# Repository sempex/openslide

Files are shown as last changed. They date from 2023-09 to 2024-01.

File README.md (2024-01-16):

# Openslide

OpenSlide is an Open-Source Camera Slider build with cost effective and well available components.

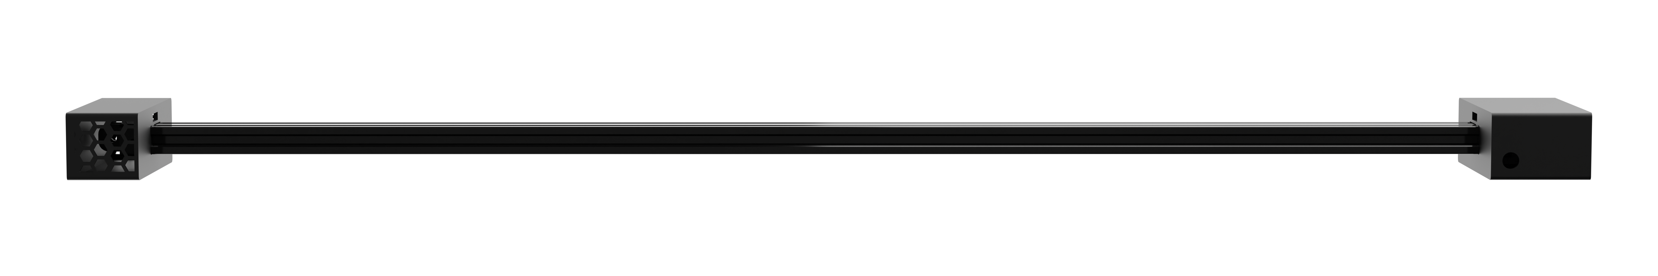
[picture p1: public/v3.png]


# How to build your own OpenSlide
Here is a basic overview on how to build your own slider. For more detailed instructions view the german [docs](doc.pdf) of the project.

## Item list

- [Rails]()  
    We use standardized V-slot aluminum extrusions as rails. These are easy to process and
    easy to obtain.
- [Motor](https://a.aliexpress.com/_mMwP7J2)  
    In order for the cart to automatically travel on the rails, it needs a motor. We have opted for the Nema 17 42 Stepper Motor.
- [Cog belt](https://a.aliexpress.com/_mKwwtJ2)  
    The V-belt is looped around the camera slider; it is responsible for enabling the cart to move along the rails with the help of the motor. Since we couldn't use a standard size, we opted for a set. This allows us to adjust the V-belt ourselves, adapting it to our specific size. This not only ensures a secure fit in terms of size but also allows us to experiment and optimize, as we can adjust the tensile strength ourselves.
- [Cart](https://a.aliexpress.com/_mOrK72g)  
    The cart is pulled back and forth on the rails by the V-belt, making it the moving element in our construction. Ultimately, the camera is attached to the cart, allowing it to move back and forth as desired. The cart has a standard size that corresponds to the rails. Additionally, it is adjustable depending on the type of rails chosen. This ensures that it works for our project.
- [Arduino]()  
    To implement the logic on the camera slider, we use an Arduino Micro-Controller. This has the advantage of being very small while providing all the necessary connections.
- [Power supply](https://a.aliexpress.com/_mNNVPCc)  
    To drive the motor, we require more power than what we can supply through the USB interface. Therefore, we need an external power supply to ensure the proper functioning of the motor.
- [End switch]()  
    To determine the position of the cart on the slider in the code, we need to perform calibration at the beginning. For this purpose, we require two switches, each attached at the start and end of the slider. These switches will notify us when there is contact with the cart.
- [Motor Driver](https://a.aliexpress.com/_m0FvBMk)  
    It is used for communication with the motor, issuing commands such as speed, current consumption, precision, and temperature to the motor.
- [Capacitor]()  
    Capacitors store electrical charges and the associated electrical energy temporarily. This ensures that a constant amount of current reaches the end device, thereby eliminating fluctuations in voltage.
- [Accessories]()  
    To attach various components, we need various screws and hot glue, among other things. We already had these utensils on hand.

## 3D Printing
Print the parts form the `cat/renders/` Folder of the GitHub Project

## Build
### Connect Arduino with Motor 
You can use the following Plan to connect the Motor with the Arduino and the driver.
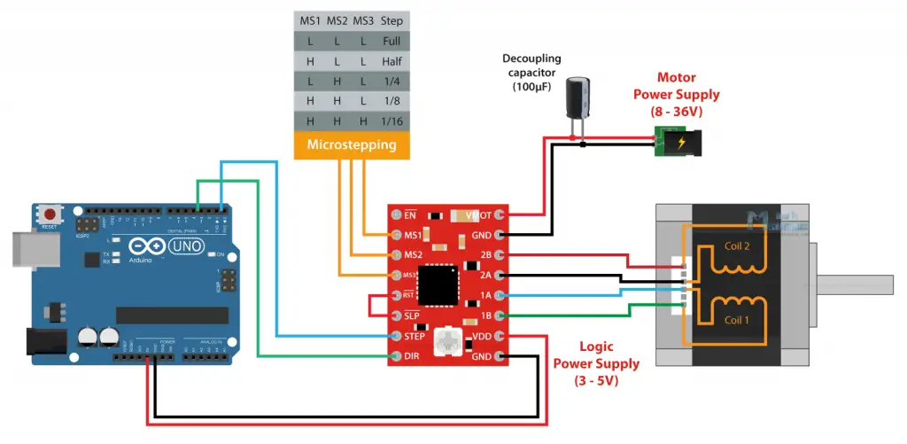
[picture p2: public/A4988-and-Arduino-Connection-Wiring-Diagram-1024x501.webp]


If you don't want to make changes to the arduino script, use following Ports:

```text
stepPin 5
dirPin 4
```

### Connect Switches
Connect the Switches to the Arduino, use following ports if you don't want to make changes to the script.

```text
#define btnOne 14
#define btnTwo 13
```

### Put everything together

Assemble the Rest of the parts using the Image of the Slider.

## User Interface

You can use our user Interface deployed on [openslide.vercel.app](openslide.vercel.app) or deploy it yourself using the node Application in `/src` directory.

Start using the Slider. Enjoy the Experiance.

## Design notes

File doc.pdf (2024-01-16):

Allgemeinbildender Unterricht

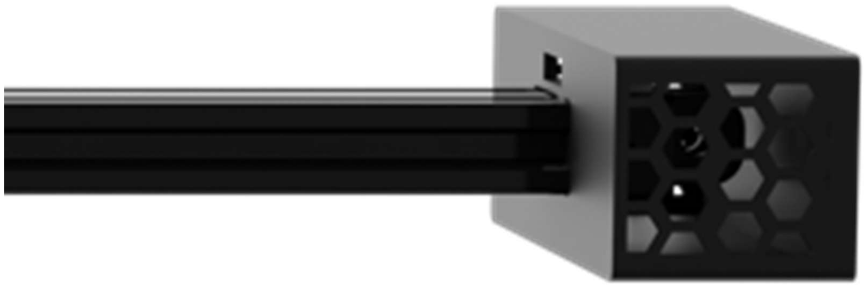
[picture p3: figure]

Abgabe: 21.12.2023 | Lehrperson:-

Klassenthema Faszination

# Entwickeln eines motorisierten Kamera-Slider (OpenSlide)

Noé Krebs, Tim Reber

Vertiefungsarbeit | OpenSlide - Kamera Slider
Tim Reber, Noé Krebs | 2

Tim Reber, Noé Krebs | 3

## Inhalt

Tim Reber, Noé Krebs | 4

Vertiefungsarbeit | OpenSlide - Kamera Slider

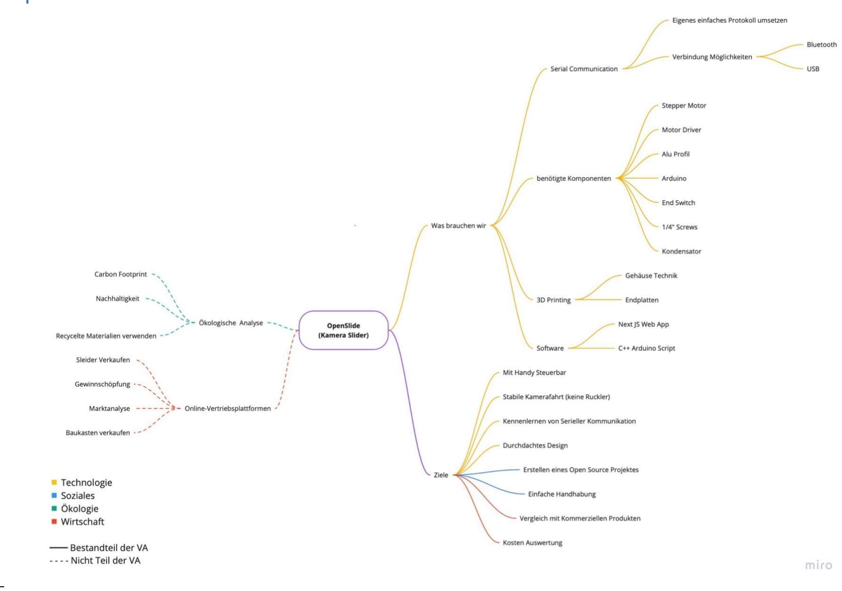
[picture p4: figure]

Tim Reber, Noé Krebs | 5

## 1. Mindmap¹

1

Mindmap, selbst erstellt

Tim Reber, Noé Krebs | 6

## 2. Einleitung²

Der motorisierte Kamera-Slider ist ein bedeutendes Werkzeug in der Videoproduktion, insbesondere für Filmemacher, die einzigartige Aufnahmen anstreben. Mit präzisen Schienen und einem leistungsstarken Motor ermöglicht dieser Slider exakte Kamerabewegungen bei anpassbarer Geschwindigkeit und Einstellungen. Diese Arbeit untersucht die technischen Aspekte des motorisierten Kamera-Sliders im Kontext der faszinierenden Welt der Videoproduktion und Technik, perfekt passend zum Klassenthema "Faszination".

Wir haben uns für dieses Projekt entschieden, da uns sowohl die Welt der Videographie als auch die Technik begeistert.

Das Projekt Open Source zu machen war für uns ein Anliegen, da wir in unserm Hobby als Entwickler viel Open-Source-Software verwenden und wir gerne auch mal etwas zu dieser Community beitragen möchten.

### 2.1. Ausganslage

In unserem Projekt wollen wir einen motorisierten Kamera-Slider selbst bauen (OpenSlide). Dieser besteht aus vorherig bestellten Einzelkomponenten, welche wir dann nach eigens kreiertem Konzept zusammenbauen. Damit man den Kamera-Slider auch ansteuern und verwalten kann, gibt es ein Web-UI, wo man Distanz, Geschwindigkeit, vordefinierte Modi und weitere Parameter konfigurieren kann. Der Code für das Web-UI wird komplett selbst geschrieben. Das gilt nicht nur für das Web-UI selbst, sondern auch für die Logik, welche der Kamera-Slider bereitstellen muss, damit die Integration mit dem Web-UI funktioniert. Damit diese beiden Komponenten zusammen kommunizieren können, werden wir ein simples Protokoll schreiben. Am Ende des Projekts wird es möglich sein, den Kamera-Slider via USB-Kabel mit einem PC zu verbinden und via Web-UI die Aktionen, welche der Kamera-Slider ausführen soll, zu bestimmen. Es wird möglich sein, eine Kamera auf dem Kamera-Slider zu befestigen. Dies via standardisiertem Schraubsystem, welches ermöglichen soll, dass möglichst viele Kameras mit unserem Slider kompatibel sind.

### 2.2. Abgrenzung

In unserem Projekt beschränken wir uns darauf, dass die Kamera nicht in verschiedene Richtungen verstellbar, sondern fix auf dem Kamera-Slider angebracht ist. Dies ist bei anderen Lösungen möglich, wir werden dies aber nicht realisieren, weil es den Zeitrahmen dieses Projekts sprengen würde.
Das Web-UI, um den Slider zu verwalten, wird öffentlich für alle erreichbar sein. Es wird keine Prüfung geben, ob man im Besitz einer unserer Kamera-Slider ist.
Das Web-UI muss nur auf offiziell unterstützen Chrome basierten Browsern funktionieren, alles andere wird von unserer Seite her nicht gewährleistet.

2

Einleitung, Selbst erstellt

Tim Reber, Noé Krebs | 7

## 3. Zielformulierungen³

- Unser Ziel ist es einen motorisierten Kamera-Slider zu entwickeln. Dabei setzen wir auf herkömmliche, erschwingliche und leicht zugängliche Komponenten. Unsere Fortschritte dokumentieren wir sorgfältig mit Bild und Text. Anschliessend veröffentlichen wir die Ergebnisse (Pläne / Code / Bilder) in einem GitHub Repository.
- Wir wollen einen umfassenden Kostenvergleich für unseren Slider im Vergleich zu ähnlichen kommerziellen Produkten erstellen. Hierzu werden wir Recherchen zu den Preisen herkömmlicher Komponenten durchführen. Diese vergleichen wir mit verfügbaren kommerziellen Kamera-Slider-Produkten im Internet.

Die Ergebnisse dieses Vergleichs werden wir in einer klaren und visuell ansprechenden Form präsentieren. Am Ende dieses Vergleichs werden wir eine Schlussfolgerung ziehen, die die Unterschiede in den Kosten zwischen unserem Slider und den kommerziellen Alternativen zusammenfasst.

- Um die technischen Grenzen unseres Sliders zu erkunden, führen wir eine Vielzahl von Tests durch. An verschiedenen Standorten nutzen wir professionelle Kameras in Kombination mit unserem Slider, um Aufnahmen anzufertigen.

Die Ergebnisse dieser Tests werden in einem eigens erstellten Bewertungsraster mit fertigen Kamera-Silder aus dem Internet verglichen und präsentiert. Hierbei werden die einzelnen Punkte für die ausgewählten Produkte auf einer Skala bewertet. Diese umfassende Bewertung erlaubt uns, die technischen Möglichkeiten unseres Sliders gründlich zu untersuchen.

3

Zielformulierung, Selbst erstellt

Tim Reber, Noé Krebs | 8

## 4. Grobplanung⁴

4

Grobplanung, Selbst erstellt

Wo-che | Arbeitsschritte | Verantwortlich* | Bemerkungen
KW 43 | Start mit der VA - Überprüfen und finalisieren der Ma-terialliste - Bestellen der Teile - Serial Protokoll ausbauen - Arbeitsjournal nachführen | Noé, Tim | Serielles Protokoll wird in NodeJS und in C++ implementiert. Alle benötigten Kompo-nenten werden online, entsprechend unserer Materialliste bestellt.
KW 44 | - Initialisierung des Web-UI Projekt - Prototyp des Web-UI deployen (im Internet verfügbar machen) - Definieren und dokumentieren der Anforderungen an das Web-UI | Noé, Tim | Erstellen eines Next.Js Projekts für das Web UI. Erste Features werden bereits gemäss Anfor-derungen eingebaut.
KW 45 | - Entwurf des 3D Slider-Modell - Modell für 3D Druck bereit machen (Slicen). - Modell drucken - Beginn Konstruktion Openslide | Noé, Tim | Eine erste Version des Modells wird konstruiert und gedruckt. Es wer-den weitere Iterationen folgen, nachdem wir mit diesem Modell Tests durchgeführt haben. 3D Modelle werden wir in Fusion 360 konstru-ieren. Wir beginnen den Bau des Sliders mit den be-stellten Komponenten. Die Schaltkreise wer-den gelötet.

Tim Reber, Noé Krebs | 9
KW 46 | - Weitere Iterationen des 3D Mo-dells konstruieren - Rendern des 3D Modells für das Web-UI - Einbinden des 3D Modells ins Web-UI | Noé, Tim | In Blender werden wir ein Produktbild ren-dern.
KW 47 | - Entwicklung der Logik auf Seite des OpenSlides | Noé, Tim | Bis zu diesem Zeit-punkt haben wir die Lo-gik für den User aus dem Web-UI entwickelt. Damit diese Aktionen umgesetzt werden kön-nen, müssen wir noch den Code für den Slider in C++ schreiben.
KW 48 | - Weiterführung der Slider Entwick-lung - Abstimmung WebUI – Silder | Noé, Tim | WebUI und Slider Firm-ware müssen aufeinan-der abgestimmt wer-den.
KW 49 | - Testen des Sliders zusammen mit dem Web-UI - Testen der Performance des Sli-ders - Beheben allfälliger Bugs | Noé, Tim | Wir müssen den Slider auf Fehler im Zusam-menhang mit dem Web-UI testen. Wir wollen herausfin-den, wo die Grenzen unseres Sliders liegen. Was ist die maximale Geschwindigkeit? Dies wäre eine berechtigte Frage, die man hier stellen könnte. Falls Fehler auftauchen müssen wir diese behe-ben.

Tim Reber, Noé Krebs | 10

*Hauptverantwortlicher: Fett. Pro Woche wird ein Hauptverantwortlicher festgelegt. Wir arbeiten jeweils an denselben Aufgaben.

KW 50 | - Finalisierung und Optimierungen des Sliders | Noé, Tim | Hier werden letzte Opti-mierungen vorgenom-men. Falls unerwartete Feh-ler in unserem Code oder in unserer Kon-struktion auftreten, ha-ben wir hier noch Zeit diese zu beheben.
KW 51 | - Abgabe der Arbeit - Kreieren von Aufnahmen | Noé, Tim | Abgabe in zwei unter-schiedlichen Ausfüh-rungen: PDF und bearbeitetes Worddokument Falls nach der Abgabe noch Zeit übrig bleibt, wollen wir mit dem Sli-der eigene Aufnahmen machen.

Tim Reber, Noé Krebs | 11

# Hauptteil

In diesem Kapitel beschreiben wir, wie wir das Endprodukt gebaut haben und gehen auf die einzelnen Aspekte des Projekts ein.

Tim Reber, Noé Krebs | 12

## 5. Konzeptionierung 5

In folgendem Kapitel haben wir die Planung und die Informationsbeschaffung beschrieben.

### 5.1. Materialliste⁶

In der folgenden Materialliste sind alle relevanten Teile zu finden, die wir für den Bau des Sliders eingeplant und bei Bedarf bestellt haben.

Tabelle 1 Material
Komponente | Beschreibung | Link
Schienen | Als Schienen verwenden wir standardisierte V-Slot Alumi-
| nium Extrusions. Diese sind einfach zu verarbeiten und
| leicht zu beschaffen.
Motor | Damit das Cart auch automatisch auf den Schienen fahren
| kann, braucht es einen Motor. Wir haben uns für den Nema
| 17 42 Stepper Motor entschieden.
Keilriemen | Der Keilriemen wird einmal um den Kamera-Slider ge-
| spannt, er ist dafür verantwortlich, dass das Cart auf den
| Schienen mit Hilfe des Motors überhaupt fahren kann. Da
| wir nicht auf eine Standardgrösse zurückgreifen konnten,
| haben wir uns dazu entschieden ein Set zu verwenden.
| Dies ermöglicht, den Keilriemen selbst zu spannen. Damit
| können wir ihn auf unsere bestimmte Grösse anpassen.
| Das hat einerseits den Vorteil, dass er von der Grösse her
| sicher passt. Andererseits können wir dadurch auch ein we-
| nig experimentieren und optimieren, da wir die Zugfestigkeit
| selbst einstellen können.
Cart | Das Cart wird durch den Keilriemen auf den Schienen hin
| und her gezogen, das heisst es ist das bewegende Element
| in unserer Konstruktion. Darauf wird dann schlussendlich
| die Kamera befestigt, damit diese in der Lage ist, nach Be-
| lieben hin und her zu fahren. Das Cart hat eine Standard-
| grösse, welche den Schienen entspricht. Es ist ausserdem
| verstellbar, je nach dem für welche Schienen man sich ent-
| schieden hat. Dadurch können wir uns sicher sein, dass es
| für unser Projekt funktioniert.
Arduino | Damit wir die Logik auf Seite des Kamera-Sliders imple-
| mentieren können verwenden wir einen Arduino Micro-Con-
| troller. Dieser hat den Vorteil, dass er sehr klein ist und alle
| benötigten Anschlüsse bietet.
Netzteil | Um den Motor anzutreiben, brauchen wir mehr Strom als
| wir über die USB-Schnittstelle zur Verfügung stellen kön-
| nen. Deswegen brauchen wir ein externes Netzteil damit
| der Motor ordnungsgemäss funktioniert.
End-Schalter | Damit wir im Code wissen können wo sich das Cart auf
| dem Slider befindet, müssen wir am Anfang eine Kalibrie-
| rung durchführen. Dafür benötigen wir zwei Schalter, wel-
| che jeweils am Anfang und am Ende des Sliders befestigt

5

Konzeptionierung, Selbst erstellt
6

Materialliste, Stark bearbeitet

Tim Reber, Noé Krebs | 13

sind und uns benachrichtigen, wenn es einen Kontakt mit dem Cart gibt.
Motor-Treiber | Er wird für die Kommunikation mit dem Motor eingesetzt
| und befiehlt dem Motor: Geschwindigkeit, Stromverbrauch,
| Präzision und Temperatur.
Kondensator | Kondensatoren speichern kurzfristig elektrische Ladungen
| und die damit verbundene elektrische Energie, dies sorgt
| dafür, dass konstant gleich viel Strom am Endgerät an-
| kommt und somit Schwankungen in der Spannung elimi-
| niert werden.
Zubehör | Um diverse Komponenten zu befestigen, benötigen wir un-
| ter anderem diverse Schrauben, sowie Heissleim. Diese
| Utensilien hatten wir bereits zur Hand.

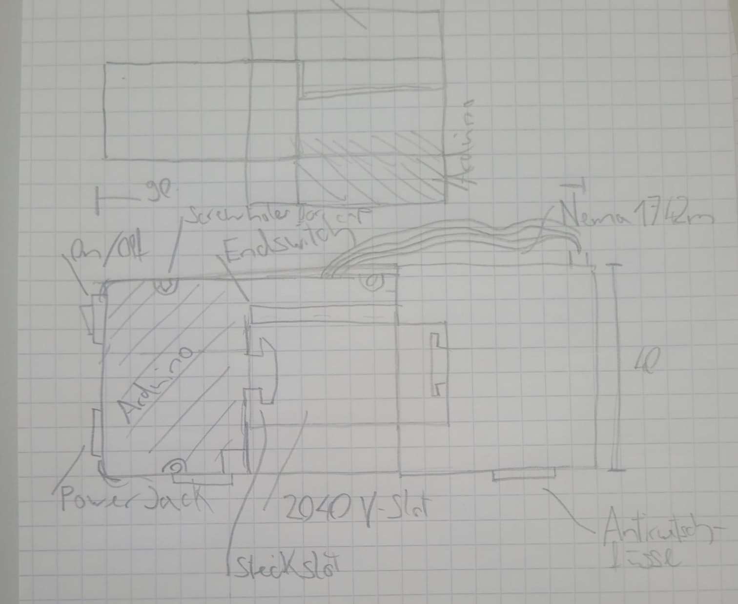
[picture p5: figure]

Tim Reber, Noé Krebs | 14

### 5.2. Technische Aspekte

In diesem Kapitel gehen wir genauer auf die technische Planung ein.

5.2.1. 3D Modellierung

Damit wir unser Projekt richtig planen und uns für die richtigen Komponenten entscheiden konnten, mussten wir eine Idee manifestieren, wie genau der Kamera-Slider schlussendlich aussehen soll.

Zum Brainstorming haben wir von Hand einige Skizzen erstellt, bis wir uns schlussendlich auf diesen groben Entwurf geeinigt haben. Dieser eignet sich am Besten, da alles auf möglichst kleinem Raum untergebracht werden kann. Ob alles genau so passen würde, wie wir uns das vorgestellt haben, ist noch unbekannt.

Abbildung 1 Originalfotografie der ersten Skizze

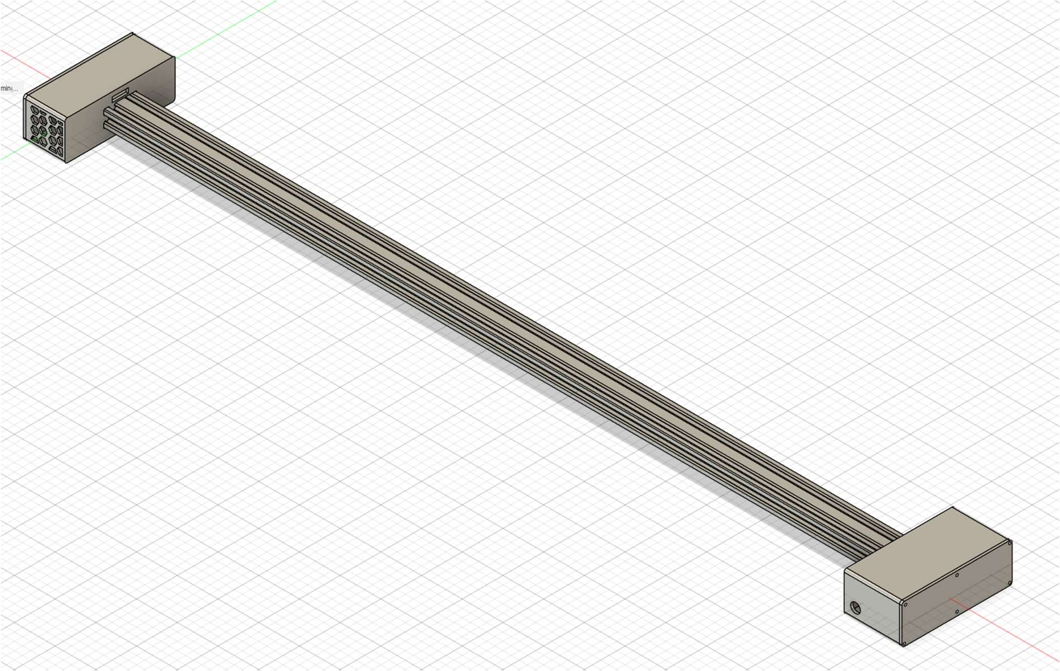
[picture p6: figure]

Tim Reber, Noé Krebs | 15

Mit dieser Skizze als Basis haben wir uns die Zeit genommen ein 3D Modell zu zeichnen. Um diese Modelle erstellen zu können, verwenden wir die Community Version der CAD Software Fusion 360 von Autodesk. Das Modell wurde Millimeter genau gezeichnet, da diese Teile mit dem 3D Drucker ausgedruckt werden. Um diese komplexen Teile passgenau drucken zu können, waren mehrere Iterationen nötig.

Abbildung 2 Finales 3D Modell des Sliders

So stellen wir uns den fertigen Kamera-Slider vor. Im rechten 3D gedruckten End-Teil, oder von uns auch Control Center genannt, wird die ganze Elektronik untergebracht, unter anderem der Motor und das Arduino, welche für die Funktionalität des Sliders verantwortlich sind. Links in der Abbildung ist das andere End-Teil. Dort ist nur ein End-Schalter und eine Umlenkrolle für den Keilriemen eingebaut.

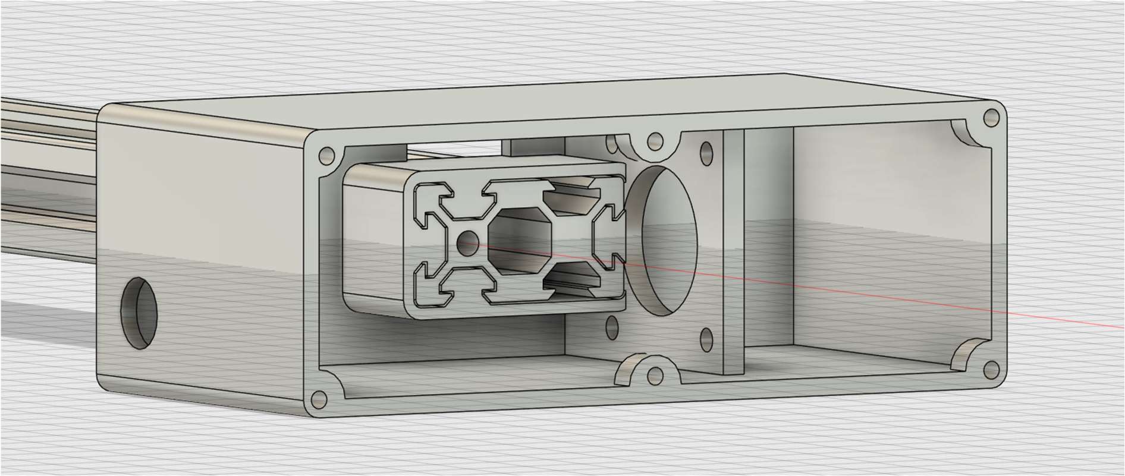
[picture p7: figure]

Tim Reber, Noé Krebs | 16

Abbildung 3 End-Teil mit Elektronik (Control Center)
Das Control Center besteht aus drei separaten Teilen, welche nach dem Ausdrucken zusammengesteckt werden können. Zur Einfachheit der Montage wird die Motorplatte unabhängig vom Gehäuse konstruiert. Der Motor wird auf der rechten Seite mit vier Schrauben an der Motorhalterung angebracht. Der Keilriemen wird später durch die Aussparungen in der Aluminiumschiene geführt.

Der Deckel kann mit vier bis sechs Schrauben am Gehäuse befestigt werden. Dies ist für beide End-Teile gleich.

Abbildung 4 End-Teil mit Umlenkrolle

7

Abbildung 6 Control Center Seitenansicht
Auf der linken Seite des Control Centers wird später die Strombuchse für den Slider montiert.

7

Power Jack (www.aliexpress.com) 19.12.2023, direkt übernommen

Abbildung 5 Strombuchse

Tim Reber, Noé Krebs | 17

Damit wir uns den Slider etwas besser vorstellen können, haben wir das 3D-Design in die Open Source Software Blender importiert.

Blender ist eine Grafiksoftware, mit welcher man Körper modellieren und animieren kann. Ausserdem kann man damit auch realistische Darstellungen von 3D Modellen erstellen. Wir haben uns genau diese Funktion zunutze gemacht und haben ein Bild des Modells erstellt.

Abbildung 7 Rendering des Sliders

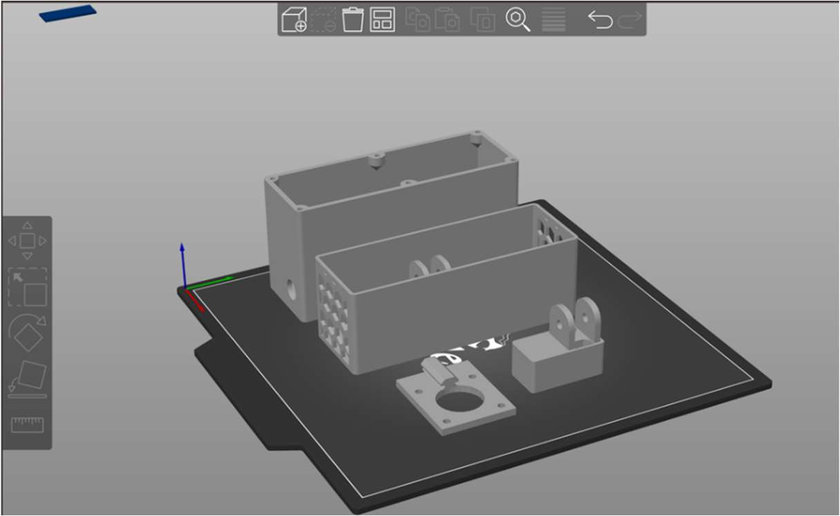
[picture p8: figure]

Tim Reber, Noé Krebs | 18
5.2.2. 3D-Druck

Im folgenden Abschnitt erklären wir, wie wir unsere zuvor erstellten 3D Modelle auf den 3D Druck vorbereiten.
Um ein Modell drucken zu können, muss es zuerst in einem Slicer aufbereitet werden. Wir verwenden den Open Source Slicer «Prusa Slicer» von Prusa. Im Slicer muss der Drucker und die Materialen, mit dem das Modell gedruckt wird, konfiguriert werden. Ausserdem kann jedes Detail des Druckvorganges genau eingestellt werden. Das ist aber in den meisten Fällen überflüssig, da der Slicer bereits sehr solide Standardwerte bietet.

Da das Druckbett zu klein ist um alle Teile gleichzeitig zu drucken, müssen wir verschiedene Druckaufträge erstellen. Im ersten Auftrag ziehen wir die wichtigsten Teile auf das Druckbett.

Abbildung 8 Druckaurag 1

Wir haben lediglich die grundlegenden Einstellungen für den Druck vorgenommen. Hierzu zählen insbesondere die Auswahl der Düsengrösse (0.20mm), die Konfiguration des Druckers (Creality Ender-3), sowie die Festlegung des verwendeten Filaments (PLA).

Für diese Einstellungen sind wiederum Standardwerte definiert, wie zum Beispiel die Flussmenge für das Filament oder die Druckbettgrösse für den Drucker. Es ist jedoch nicht notwendig, diese selbst zu definieren, da entsprechende Profile vom Slicer bereitgestellt werden.

Abbildung 9 Slicer Grundeinstellungen

Nachdem alle Teile eingefügt und die entsprechenden Einstellungen vorgenommen wurden, ist es nun an der Zeit, das Projekt zu "slicen". Dieser Prozess bezeichnet die Umwandlung des 3D-Modells in Anweisungen, die der 3D-Drucker verarbeiten kann.

Anschliessend kann der Auftrag an den Drucker geschickt und gestartet werden.

Tim Reber, Noé Krebs | 19

### 5.2.3. Eigenes Protokoll

Das Problem bei der seriellen Kommunikation, so wie wir sie verwenden ist, dass jeder Charakter als einzelnes Byte ans Arduino gesendet wird.

Wenn man das Wort: “beispiel” ans Arduino sendet, interpretiert es jeden Buchstaben einzeln: «b», «e», «i», «s», «p», «i», «e», «l». Das ist für unseren Anwendungszweck nicht geeignet. Wenn wir zum Beispiel eine Position vom Web-UI ans Arduino senden wollen, wird bereits mehr als ein Zeichen in Anspruch genommen, da wir einen Startpunkt und einen Endpunkt senden müssen.

Damit wir mehr als nur ein einzelnes Zeichen senden oder empfangen können, haben wir ein simples Protokoll entwickelt. Wir haben im Code definiert, dass wir auf ein Startzeichen warten. Dies ist in unserem Fall «<» kleiner als. Das heisst, wenn ein solches Zeichen kommt, wissen wir, dass jetzt eine neue Nachricht beginnt.

Wir haben ebenfalls ein Schlusszeichen definiert: «>» grösser als. Wenn dieses Zeichen erscheint, wissen wir, dass die Nachricht komplett ist. Allen Charakteren, welche sich jetzt zwischen diesen beiden Zeichen befinden, werden nun zusammengefügt und entsprechen der ganzen Nachricht.

Zum Verständnis: Wenn wir jetzt eine Start-und End-Position ans Arduino senden wollen, müsste die Nachricht wie folgt aussehen: «<MOVE:start=10,end=35>». MOVE ist der auszuführende Befehl. Start und end sind beliebige Parameter die zusätzlich zum Befehl übergeben werden. Alles zusammen entspricht einer ganzen Nachricht.

Bandbreite

Da unser Protokoll auf Buchstaben basiert, braucht es viel mehr Bandbreite als ein Bit basiertes Protokoll. Wir sind diesen Kompromiss eingegangen, da bei uns die übertragene Datenmenge klein ist und es verständlicher ist.

Um mit unserem Protokoll diese Nachricht (<MOVE:start=10,end=35>) zu übermitteln, braucht es rund 25 Bytes.

Mit einem rein binären Protokoll könnte man diese Zahl auf unter 5 Bytes bringen, da keine unnötigen Informationen übertragen werden, die nur zur Verständlichkeit dienen.

Error Korrektur

Bei der Übertragung von Daten besteht immer die Möglichkeit, dass einzelne Buchstaben oder Bits fehlerhaft übertragen werden. Das bedeutet, dass der Empfänger nicht genau das empfängt, was gesendet wurde. Um dies zu verhindern, integrieren viele Protokolle sogenannte Fehlerkorrekturmechanismen. Diese ermöglichen es, bis zu einem bestimmten Prozentsatz an korrekten Daten die ursprüngliche Nachricht wiederherzustellen.

Auch hier hat unser Protokoll einen Nachteil. Allerdings spielt es bei solch kleinen Datenmengen und für unsere Anwendungen kaum eine Rolle, wenn wir keine Error Korrektur verwenden.

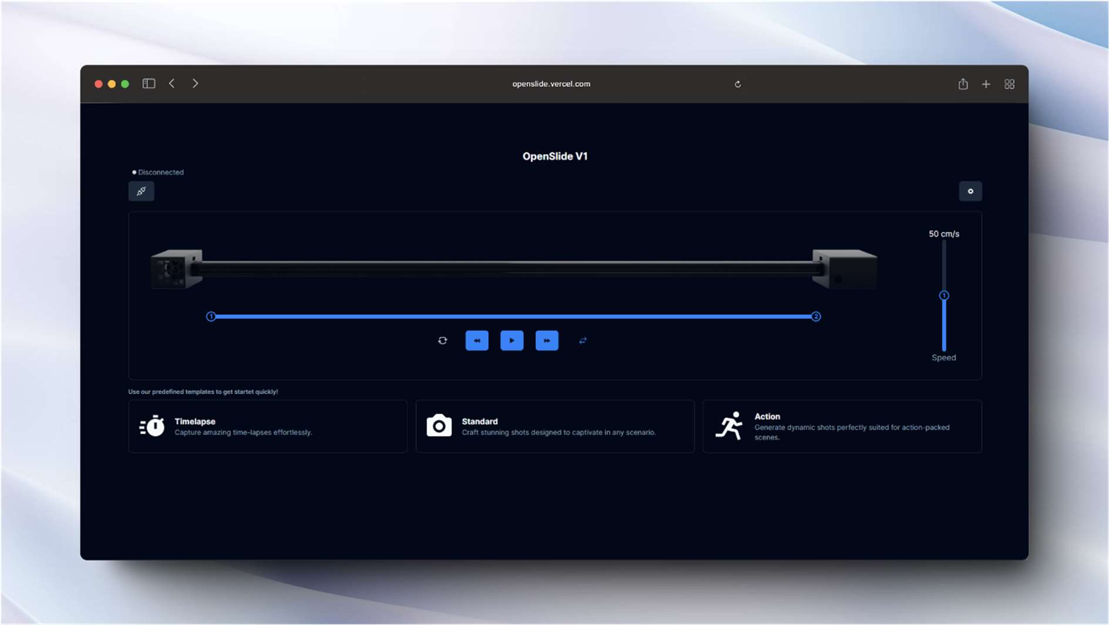
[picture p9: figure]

Tim Reber, Noé Krebs | 20

## 6. Benutzeroberfläche⁸

Die Benutzeroberfläche ist einer der Schwerpunkte unseres Sliders, in diesem Kapitel erklären wir, wie sie aufgebaut ist.

### 6.1. Technologie

Für die Benutzeroberfläche haben wir Gebrauch von einigen nützlichen Technologien gemacht. Die Relevantesten haben wir unten kurz beschrieben.

### 6.1.1. Next.js

Bei der Entwicklung des Web-UI haben wir auf NextJS gesetzt, NextJS ist ein Open-Source Framework, das von dem Unternehmen Vercel betreut wird. Dieses Framework erlaubt es React basierte Web-Anwedungen mit serverseitigem Rendering und statischer Website-Generierung zu erstellen. Die ganze Benutzeroberfläche wurde in der Sprache TypeScript geschrieben. TypeScript wurde von Microsoft entwickelt und fügt Typisierung zu JavaScript hinzu.

### 6.1.2. Tailwindcss

Tailwind CSS ist ein beliebtes CSS-Framework, das auf Utility-Klassen basiert und die Gestaltung von Webseiten beschleunigt. Es ermöglicht uns, schnell und effizient responsive Designs zu erstellen, indem Klassen direkt im HTML-Code eingebettet werden, anstatt CSS-Klassen von Grund auf neu zu schreiben. Mit einer umfangreichen Dokumentation und einer aktiven Community hat sich Tailwind CSS zu einem starken Werkzeug für die Frontend-Entwicklung entwickelt.

8

Benutzeroberfläche, Selbst erstellt

Abbildung 10 Benutzeroberfläche

Tim Reber, Noé Krebs | 21

### 6.1.3. Vercel.com

Vercel, die Macher von NextJS bieten einen kostenlosen Service an wo wir unser Projekt bereitgestellt haben. Das heisst, sie sind verantwortlich, dass unsere Benutzeroberfläche auf folgender Adresse: openslide.noekrebs.ch die ganze Zeit online und für Jeden verfügbar gemacht wird.

### 6.2. Features

Unser Web-UI bietet eine Vielzahl von nützlichen Funktionen für die Steuerung und Anpassung unseres Kamera-Sliders. Der Benutzer hat die volle Kontrolle über die Fahrt der Kamera auf dem Slider. Von wo sie startet und wohin sie sich bewegt, ist ganz nach den Wünschen des Benutzers einstellbar. Aber das ist noch nicht alles!

Der Benutzer kann nicht nur die Start und Zielpunkte festlegen, sondern auch die Geschwindigkeit definieren, mit der sich die Kamera über den Silder bewegen soll. Diese Flexibilität ermöglicht es, die Bewegung genau nach den eigenen Bedürfnissen anzupassen.

Ausserdem kann man auch die Bewegungsrichtung des Silders ändern.

Eine weitere spannende Option ist der Loop-Modus. In diesem Modus fährt der Silder immer wieder von Start zu Endpunkt bis der Benutzer diese Funktion wieder deaktiviert. Diese Wiederholungsfunktion eröffnet aufregende Möglichkeiten für kreative Aufnahmen.

Wir haben eine Auswahl an vordefinierten Kombinationen von Geschwindigkeit und Position definiert, worauf man auch immer zurückgreifen kann, sollte man sich gerade nicht sicher sein welche Einstellungen zu der aktuellen Szene am Besten passen. Diese nennen wir Templates. Es gibt 3 verschiedene Varianten.

- Timelapse: Eignet sich hervorragend für Timelapse-Aufnahmen, das Cart fährt dementsprechend extrem langsam auf dem Slider, wobei aber immer noch flüssige und ruckfreie Aufnahmen entstehen.
- Standard: Dieser Modus eignet sich perfekt für die meisten Situationen und entspricht den Standardwerten.
- Action: Dieser Modus ist für eher schnellere, actionreiche Szenerien geeignet. Er ist schneller und fährt eine kürzere Distanz als der Standardmodus, um diese Emotionen in die Aufnahmen zu übertragen.

Das Web-UI hat eine zusätzliche wichtige Aufgabe: Es ist dafür verantwortlich, die Befehle an den Slider zu übertragen. Dies geschieht mit Hilfe der Web-Serial API. Nachdem der Benutzer den Slider über USB mit seinem Endgerät verbunden hat, werden die ausgeführten Befehle mit unserem eigenen Protokoll über USB an den Slider übertragen.

Tim Reber, Noé Krebs | 22

## 7. Arduino⁹

Das Arduino wird verwendet, um die Befehle, welche über das Web-UI gesendet werden effektiv umzusetzen. Das Arduino ist via USB-Kabel mit dem PC verbunden und kann darüber mit dem Web-UI kommunizieren.

Das Arduino muss in der Lage sein, die vom Web UI kommenden Befehle umzusetzen. Dabei muss es eventuell auch die Werte umrechnen. Das Web UI ist für jeden OpenSlide gleich, deswegen haben wir darauf geachtet, dass sich möglichst alle Hardware spezifische Logik auf dem Arduino befindet.

### 7.1. Kalibrierung

Das Arduino erfasst jede Position als Prozentwert von 0 bis 100, wobei 0 die ganz Linke Seite repräsentiert und 100 die rechte Seite. Da der Motor nach dem Einschalten nicht weiss, wo sich der Wagen momentan auf dem Slider befindet, erfolgt zunächst eine Kalibrierung. Der Motor startet bei Schritt 0 (nicht zwangsläufig ganz links oder rechts) und bewegt sich dann um eine bestimmte Anzahl von Schritten, bis er einen der Endschalter erreicht. An dieser Stelle setzt er seinen neuen Nullpunkt. Von diesem neuen Nullpunkt aus fährt er nun zum anderen Ende, um genau zu bestimmen, wie lang der Slider ist.

Von jetzt an kann der Slider Positionen in Form von Schritten entgegennehmen.

Beispiel:
- 0 = Ganz links
- 2000 = Ganz rechts
- 1000 = In der Mitte

Wir können nun diese Formel verwenden um den Wertebereich 0 – 100 in 0 – 2000 umzuwandeln.

Y = (x - in_min) * (out_max - out_min) / (in_max - in_min) + out_min

X ist der umzuwandelnde Wert. In_min ist der minimale Wert von x (0), in_max der maximale Wert von X (100). Out_max (2000) ist der grösstmögliche Ausgabewert, out_min (0) der Kleinste. Dem Motor wird jetzt der y-Wert übergeben und er wird sich an die gewünschte Position bewegen.

Dank dieser Umrechnung kann der Slider nun Positionen in Form von Prozentwerten verarbeiten und das Web-UI benötigt keine Informationen über die Länge des Sliders um ihn zu steuern.

### 7.2. Kommunikation

Das Arduino wird über unser eigenes Protokoll, welches im Kapitel «Eigenes Protokoll» ausführlich beschrieben wurde, angesteuert.

9

Arduino, Selbst erstellt

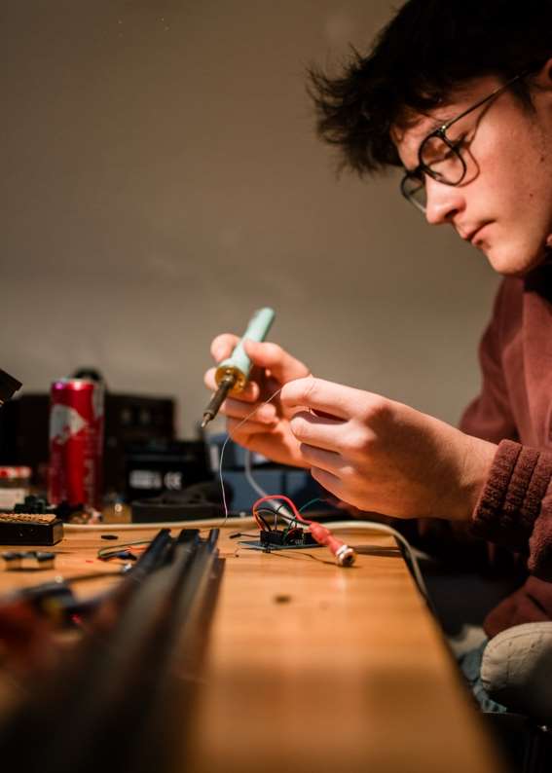
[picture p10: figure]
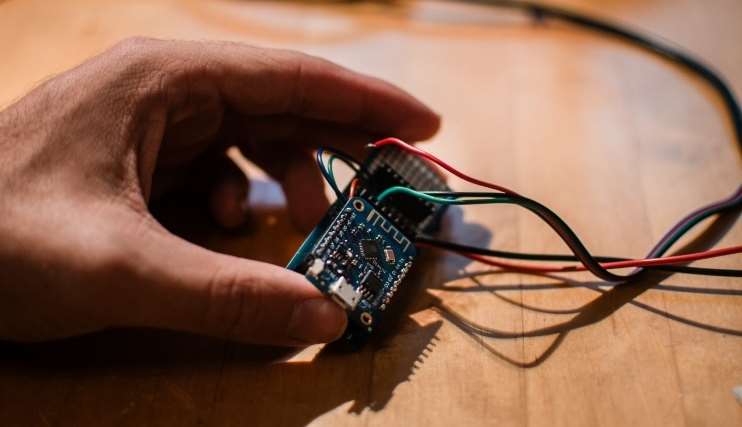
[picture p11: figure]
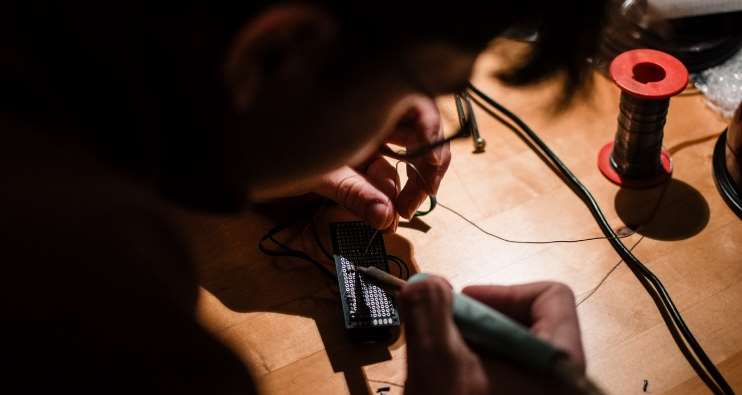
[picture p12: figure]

Tim Reber, Noé Krebs | 23

## 8. Umsetzung¹⁰

Nachdem wir intensiv über Software und Hardware nachgedacht haben, dokumentieren wir in dem folgenden Kapitel die konkrete Umsetzung.

### 10 Umsetzung, Selbst erstellt

Abbildung 11:Einblick Umsetzung

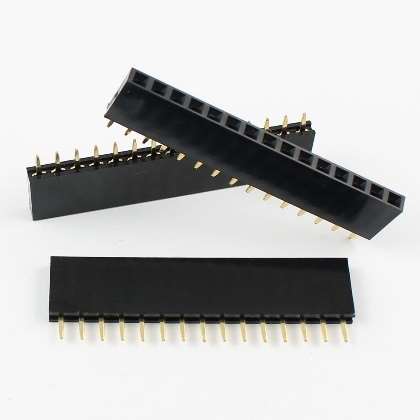
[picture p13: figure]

Tim Reber, Noé Krebs | 24

### 8.1. Control Center

Kern unseres Sliders ist der Arduino Micro Controller. Dieser besteht aus den drei unten aufgezeigten Komponenten, welche ausschliesslich für die Ausführung der logischen Operationen auf dem Kamera-Slider verantwortlich sind.

Den Treiber und das Arduino haben wir nicht direkt mit der Leiterplatte verlötet, sondern über Leiterplattenbuchsen. So können die beiden Komponenten bei einem Ausfall einfach ersetzt werden, ohne dass sie neu gelötet werden müssen.

Abbildung 12 Leiterplaenbuchsen¹¹
Um sicherzustellen, dass die Geräte miteinander kommunizieren können, wurden alle genannten Teile miteinander durch versteckte Kabel verbunden.
Abbildung 13 A4899¹² | Abbildung 14 Leiterplae 13 Abbildung 15 Arduino D1 Mini¹⁴

### 11 Leiterplattenbuchsen (https://forum.arduino.cc/ ) 19.12.2023, direkt übernommen

12 A4899 (https://davincilab.co.za/products/a4988-stepper-driver ) 19.12.2023, direkt übernommen

### 13 Platte (https://www.amazon.de/) 19.12.2023, direkt übernommen

14 Arduino (https://www.berrybase.ch/d1-mini-lite-esp8285-entwicklungsboard ) 19.12.2023, direkt übernommen

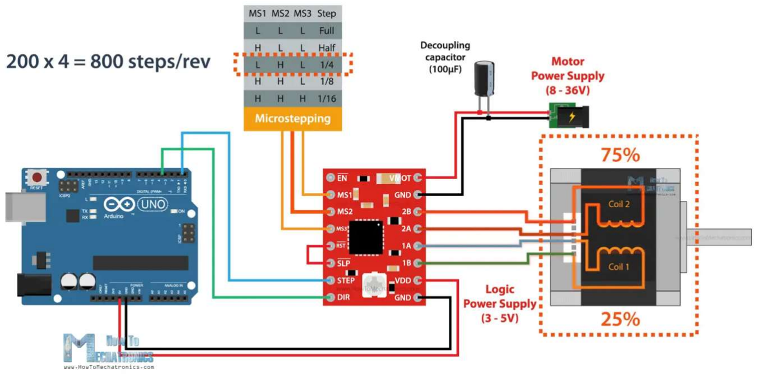
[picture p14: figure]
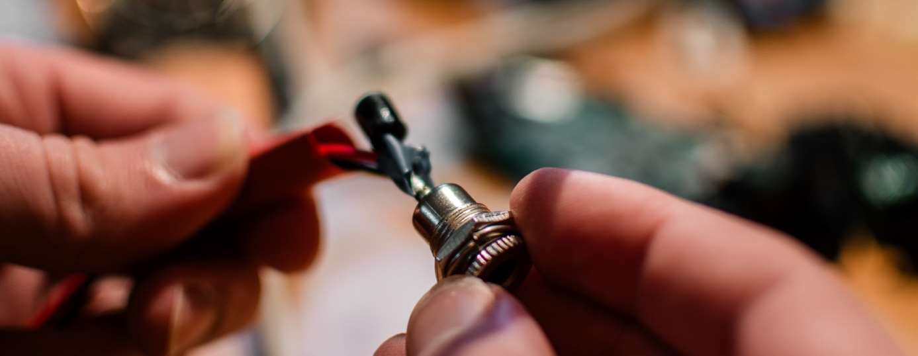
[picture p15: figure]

Tim Reber, Noé Krebs | 25

Damit wir genau wissen, welche Anschlüsse wir verbinden müssen, haben wir dieses Schema als Vorlage genommen.

Abbildung 16 Verkabelung Driver, Stepper, Arduino¹⁵
Die ganze Steuereinheit wird durch ein 12v 2A Netzteil mit Strom versorgt. Damit das möglich ist, haben wir den Power Jack mit dem Driver verbunden. Nun würde das Konstrukt bereits funktionieren, allerdings könnten Schwankungen in der Spannung die elektronischen Teile beschädigen. Um das zu verhindern, schalten wir einen 1000 Mikrofarad-Kompensator direkt hinter dem Stromstecker dazwischen. Wo sich dieser allerdings befindet, spielt keine Rolle, solange er mit den Masse und 12V Versorgungspins verbunden ist.

Abbildung 17 Power Jack mit Kompensator

15 (Howtomechatronics https://howtomechatronics.com ) 28.11.2023, direkt übernommen

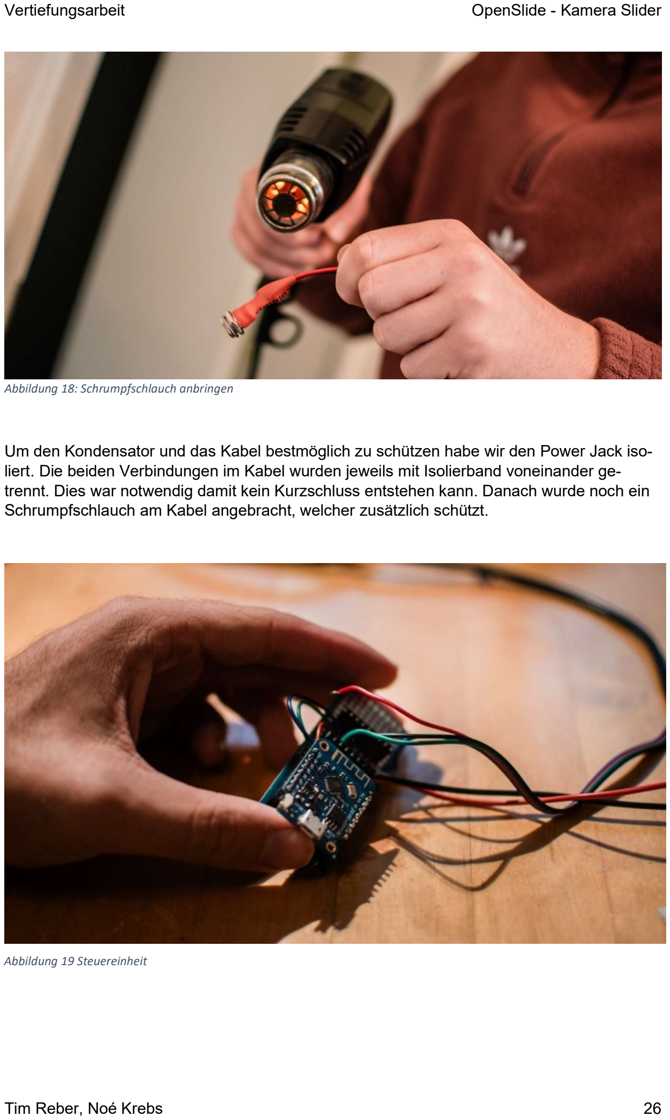
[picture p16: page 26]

Tim Reber, Noé Krebs | 26

Abbildung 18: Schrumpfschlauch anbringen

Um den Kondensator und das Kabel bestmöglich zu schützen habe wir den Power Jack isoliert. Die beiden Verbindungen im Kabel wurden jeweils mit Isolierband voneinander getrennt. Dies war notwendig damit kein Kurzschluss entstehen kann. Danach wurde noch ein Schrumpfschlauch am Kabel angebracht, welcher zusätzlich schützt.

Abbildung 19 Steuereinheit

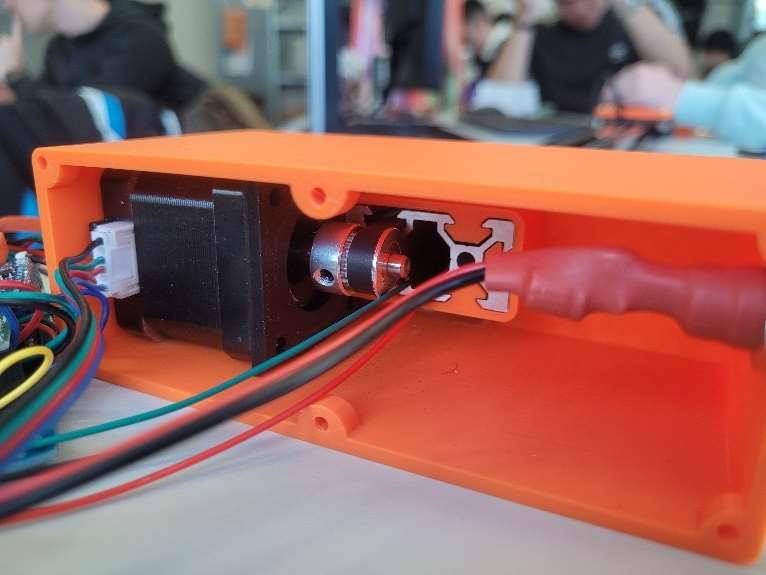
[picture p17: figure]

Tim Reber, Noé Krebs | 27

Daraufhin wurden alle Komponenten in die zuvor gedruckten Teile eingebaut. Auf der linken Seite ist der Nema 17 Stepper Motor zu sehen und auf der rechten Seite der Stromstecker.

Diese Ansicht ähnelt bereits sehr der Originalskizze.

### 8.2. End Teil mit Umlenkrolle

Die Kabel der Endschalter wurden durch die Mitte der V-Slots Schienen geführt, so dass von aussen keine Kabel sichtbar sind. Auf dem Bild sind sie links neben der Rolle zu erkennen.

Die Umlenkrolle für den Riemen wurde mit Hilfe einer Schraube an der dafür vorgesehenen Halterung montiert. Der Riemen verläuft durch einen der V-Slots.

Abbildung 21 Umlenkrolle

Abbildung 22 Endschalter
Die Endschalter wurden auf beiden Seiten direkt über der Schiene in die dafür vorgesehene Aussparung verleimt, so dass sie vom Cart gedrückt werden können.

Abbildung 20 Control Center auau

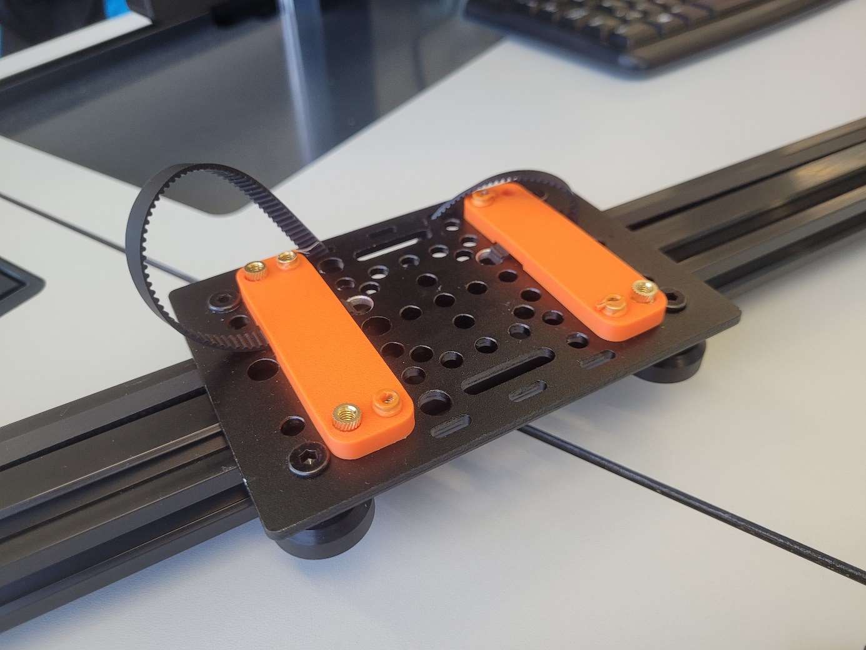
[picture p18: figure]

Tim Reber, Noé Krebs | 28

### 8.3. Kamerawagen

Auf dem Kamerawagen (Cart) wird später die Kamera montiert. Wie raffiniert er aufgebaut ist wird in folgendem Kapitel erklärt.

Abbildung 23 Wagen
Der Riemen wird auf dem Wagen mit Hilfe von zwei angeschraubten Platten gespannt und fixiert. Diese Platten werden auf die Oberfläche des Wagens gedrückt, wodurch der Riemen eingeklemmt wird und sich nicht mehr bewegen kann. Um die 3D-gedruckten Platten zu befestigen, wurden Gewinde eingeschmolzen.

Abbildung 24 Messing Gewinde zum einschmelzen ¹⁶

### 16 Threaded Inserts (https://shop4fasteners.co.uk/) 19.12.2023, direkt übernommen

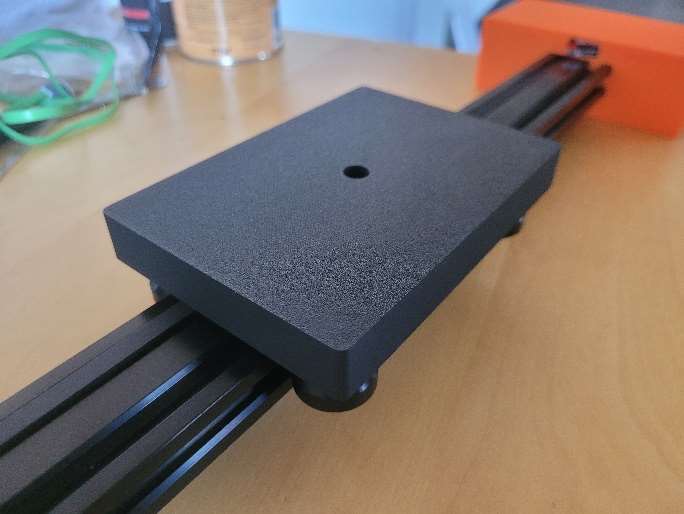
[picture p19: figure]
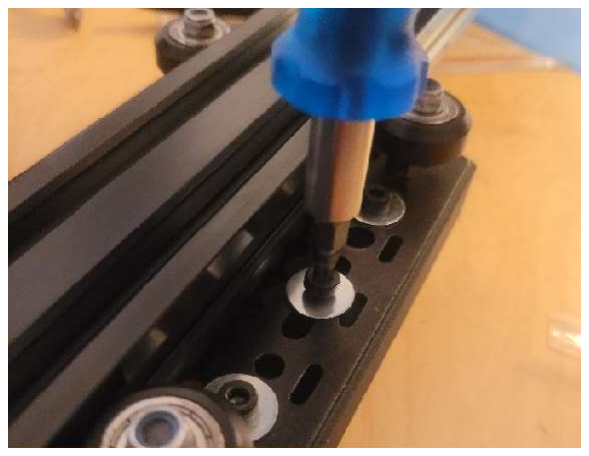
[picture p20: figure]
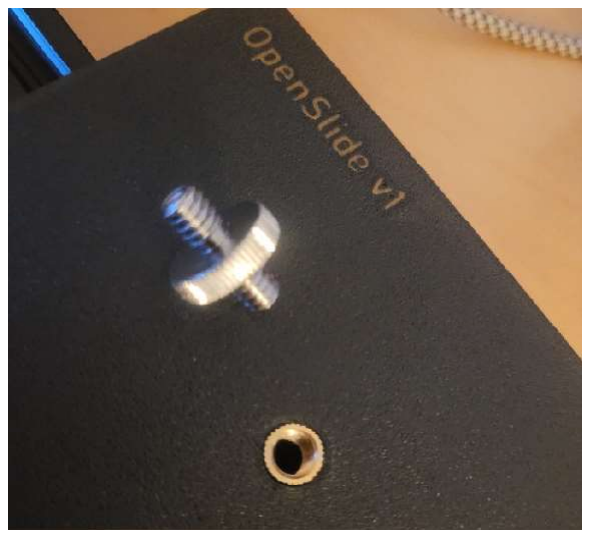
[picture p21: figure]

Tim Reber, Noé Krebs | 29

### 8.3.1. Abdeckung

Damit die Kamera befestigt werden kann und der Slider etwas schöner daher kommt haben wir eine Abdeckung angefertigt, die wir mit zwei Schrauben am Cart montiert haben. Auch hier haben wir wieder Messing Gewinde verwendet.

Abbildung 25 Montage Cart Abdeckung | Abbildung 26 Cart mit Abdeckung

In der Mitte der Abdeckung wurde ebenfalls ein Gewinde eingeschmolzen. Es handelt sich um ein 1/4 Zoll Gewinde, da dies der Standard für Kameras ist.

Mit Hilfe von einem Multi-Filament/Farbdruck konnte oben links noch ein Lable eingefügt werden.

Abbildung 27 1/4 Zoll Gewinde für Kamera

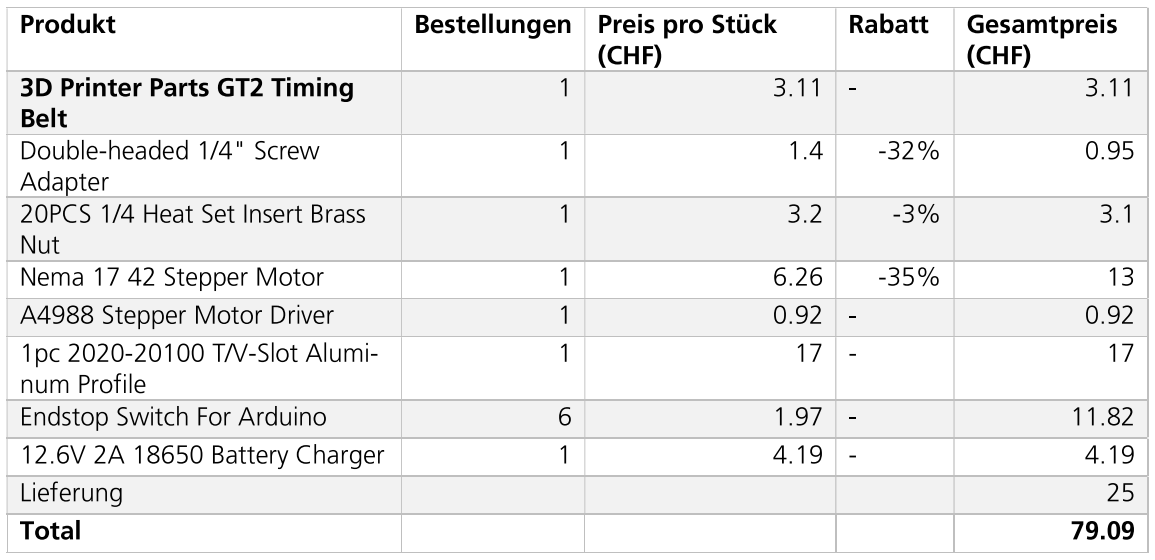
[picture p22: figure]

Tim Reber, Noé Krebs | 30

## 9. Preisvergleich¹⁷

In folgendem Kapitel haben wir einen Preisvergleich zwischen dem OpenSlide V1 und dem GVM Motorized Camera Slider aufgestellt. Der GMV Slider ist ein typischer Mittelklasse Slider, der im Internet erhältlich ist.

Der Fokus liegt dabei nicht nur auf den finanziellen Aufwendungen, sondern auch darauf, welche Funktionen und Eigenschaften diese beiden Slider mit sich bringen.

### 9.1. Preisaufstellung

Um den Preis zu kalkulieren, haben wir für sämtliche Produkte aus der Materialliste die Kosten aufgeführt und im Anschluss summiert.

Nicht im Preis enthalten ist das Material, das vom 3D-Drucker für die Herstellung der Teile verwendet wurde. Dabei wurde nicht nur Material für das finale Produkt verwendet, sondern es mussten auch zahlreiche Modelle zum Zwecke der Entwicklung erstellt werden. Es handelt sich hierbei lediglich um wenige Franken, da das verwendete Material äusserst kostengünstig ist.

Tabelle 2 Preiskalkulaon

Preise können je nach Bestelldatum variieren.

### 17 Preisvergleich, Selbst erstellt

Tim Reber, Noé Krebs | 31

### 9.2. Featurevergleich

In folgender Tabelle haben wir die wichtigsten Features und Eigenschaften zusammengefasst und den zuvor kalkulierten Preis eingefügt.

Tabelle 3 Slidervergleich
Eigenschaft OpenSlide V1 | GMV¹⁸ Slider
Preis | 79.-* | 266.-
Länge | 100 cm | 83 cm
Steuerung | Webapp | Fernbedienung
Akku | Nein** | Ja
Zeitraffer Funktion | Ja | Ja
Open Source | Ja | Nein
Lautstärke | Je nach Geschwindigkeit eher laut und ist nicht für Aufnahmen mit Ton geeig- net. | Angeblich leise und auch während Interviews gut ver- wendbar ***

* für diesen Preis kann man sich lediglich die Komponenten kaufen. Der Slider kommt nicht ferg zusammengebaut und ist nicht funkonsfähig.

** kann einfach erweitert werden mit einem standardmässigen 12v Akku.

*** basierend auf Informaonen aus dem Internet.

### 18 GMV Slider Info (https://gvmled.com/gvm-slider-80/), stark bearbeitet

Tim Reber, Noé Krebs | 32

### 9.3. Schlussfolgerung

Beide Slider weisen sowohl Vor- als auch Nachteile auf. Neben offensichtlichen Vorteilen wie Preis und Länge gibt es auch versteckte Aspekte. Der OpenSlide übertrifft insbesondere in Erweiterbarkeit und Anpassungsfähigkeit. Es besteht jederzeit die Möglichkeit, Funktionen von uns oder aus der Open-Source-Community hinzuzufügen, was ein enormes Potenzial bietet. Ein klarer Nachteil ist jedoch, dass der OpenSlide V1 nicht als fertiges Produkt erhältlich ist, im Gegensatz zum GMV Slider.

Der GMV Slider punktet auch im Bezug auf die Lautstärke. Die speziell für diesen Zweck entwickelten Motoren des GMV Sliders ermöglichen einen leiseren Betrieb im Vergleich zum OpenSlide. Ein weiteres Komfortmerkmal, das der OpenSlide V1 derzeit nicht bietet, ist ein integrierter Akku. Obwohl der OpenSlide auf Branchenstandards basiert und problemlos mit einem externen 12-Volt-Akku betrieben werden kann, ist dies beim GMV von Haus aus möglich.

In Bezug auf Softwarefunktionen hat der OpenSlide V1 wiederum klare Vorteile. Dies liegt daran, dass der gesamte Code Open Source ist und leicht erweitert werden kann. Der Open-Slide bietet bereits heute viele Einstellungsmöglichkeiten, so dass er genau an die jeweilige Situation angepasst werden kann. Der GMV kann zwar auch über eine Fernbedienung gesteuert werden, jedoch sind grössere Softwareupdates hier eher weniger zu erwarten.

Nachdem wir zahlreiche Fakten verglichen haben, bleibt die Frage: Welchen Slider sollte ich jetzt kaufen?

Ich kaufe einen OpenSlide V1, wenn...

- Ich viel über verwendete Komponenten, Code und Hardware lernen möchte und bereits mit den technischen Grundlagen vertraut bin.
- Ich einen kostengünstigen Slider für eine beliebige Kamera suche und Aufnahmen machen möchte, bei denen der Ton nicht oberste Priorität hat.

Ich kaufe einen GMV Slider oder ähnliches, wenn...

- Ich wenig selbst konfigurieren möchte und vor allem Aufnahmen machen will, bei denen der Ton oberste Priorität hat.
- Ich kein Interesse am Selbstbau habe, sondern einen einsatzbereiten Slider für meine Aufnahmen benötige.
- Ich bereit bin mehr Geld auszugeben.

Tim Reber, Noé Krebs | 33

## 10. Stress-Test¹⁹

Das Wichtigste am Kamera Slider ist seine eigentliche Funktion. Um herauszufinden, wo die Grenzen liegen, haben wir einige spannende Tests durchgeführt, um die Funktionalität des Sliders zu gewährleisten. Dabei geht es nicht nur um den Slider selbst, sondern auch um die Komponenten, die mit ihm zusammen verwendet werden, zum Beispiel die Kameras.

Damit wir die ganzen Kriterien beurteilen können, gibt es eine fünfstufige Gütestufenskala. Alle Tests werden mit dieser Skala bewertet. Dies ist auch für uns eine grosse Hilfe, da wir so herausfinden können welche Einstellungen wir zum Beispiel für die maximale Geschwindigkeit verwenden können. Hierbei geht es nicht darum den Slider möglichst schnell zu machen, sondern eine Einstellung zu finden, welche zwar eine hohe Geschwindigkeit ermöglicht, gleichzeitig aber auch zuverlässig funktioniert.

Tabelle 4 Gütestufen

Hervorragend
Gut
Befriedigend
Schlecht
Sehr schlecht

### 10.1. Geschwindigkeit

Hier haben wir versucht die optimale maximale Geschwindigkeit für den Slider herauszufinden.
Tabelle 5 Vergleich Geschwindikeit
Test | Gütestufe | Beschreibung | Auswertung
Geschwindigkeit auf 1500 spp | Schlecht | Der Motor wird mit einer Maxi-malgeschwindigkeit von 1500 spp konfiguriert. | Der Motor läuft sehr zuverlässig, jedoch sind die einzelnen Schritte des Motors in den Aufnahmen er-kennbar.
Geschwindigkeit auf 3000 spp | Hervorra-gend | Der Motor wird mit einer Maxi-malgeschwindigkeit von 3000 spp konfiguriert. | Die Zuverlässigkeit zum vorheri-gen Test hat nicht abgenommen, die Geschwindigkeit hat sich enorm verbessert. Der Slider kann so optimal verwendet wer-den.
Geschwindigkeit auf 3500 spp | Befriedi-gend | Der Motor wird mit einer Maxi-malgeschwindigkeit von 3500 spp konfiguriert. | Die Zuverlässigkeit nimmt dras-tisch ab, der Motor kennt teil-weise die aktuelle Position nicht mehr. Die Geschwindigkeit ist zwar nochmals höher, schluss-endlich ist das Risiko auf Versa-gen zu hoch, um die Geschwin-digkeit zu rechtfertigen.

*spp steht für «steps per seconds» also die Anzahl Schrie, welcher der Motor in einer Sekunde macht.

### 19 Stress-test, Selbst erstellt

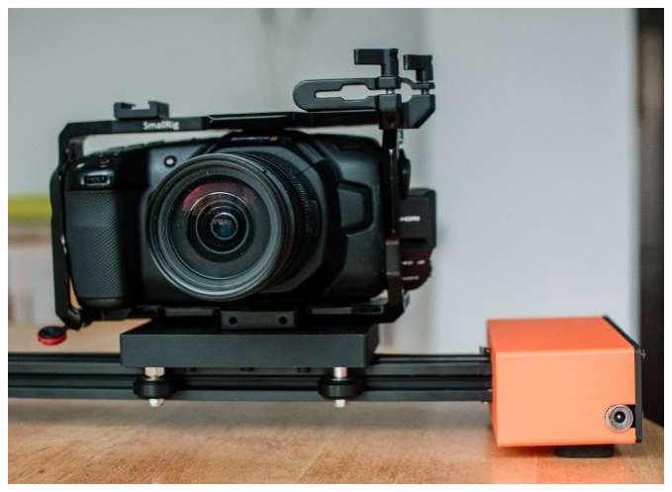
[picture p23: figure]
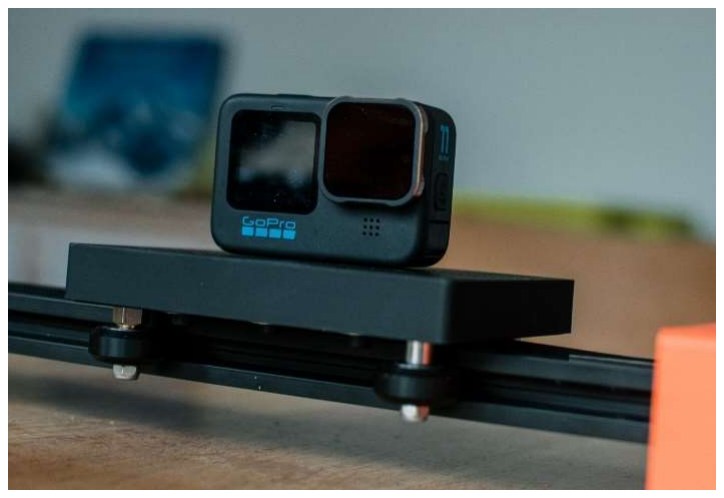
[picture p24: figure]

Tim Reber, Noé Krebs | 34

### 10.2. Kameras

Hier haben wir getestet welche Kamera sich besonders eignet für unseren Slider. Für diesen Test wurden drei verschiedene Arten von Kameras auf dem Slider montiert.

Tabelle 6 Kameravergleich

Abbildung 28 Blackmagic Design Pocket Cinema Camera 4K

Abbildung 29 GoPro Hero 11

Test | Gütestufe | Beschreibung | Auswertung
GoPro Hero 11 | Hervorra-gend | Hier wurde der Slider in Kom-bination mit der GoPro Hero 11 verwendet. | Der Slider hat mit der GoPro kei-nerlei Probleme, er kann die Ka-mera problemlos hin und her be-wegen. In den Aufnahmen sind keinerlei Ruckler zu erkennen.
bmpcc 4k | Hervorra-gend | Hier wurde der Slider in Kom-bination mit der Blackmagic Design Pocket Cinema Camera 4K verwendet. | Der Slider hatte auch mit dieser Kamera keine Probleme. Auf-grund des grösseren Gewichts der Kamera hätten wir erwartet, dass der Slider langsamer oder träge reagiert. Das war aber nicht der Fall.
Smartphone | Hervorra-gend | Hier wurde der Slider in Kom-bination mit dem Samsung Galaxy S20 FE verwendet. | Auch hier hatte der Slider keine Probleme beim Bewegen des Smartphones. Auch die Aufnah-men weisen hier keinerlei Ruckler auf.

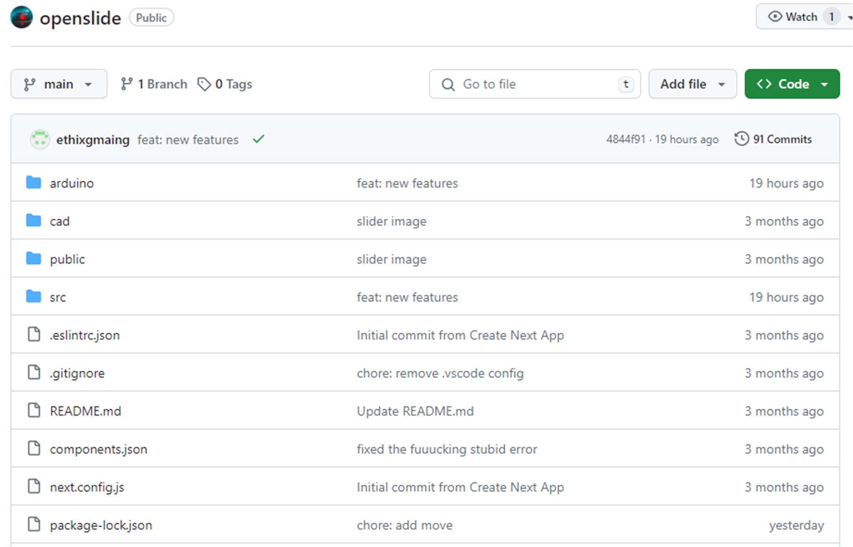
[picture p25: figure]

Tim Reber, Noé Krebs | 35

## 11. Veröffentlichung²⁰

Von Anfang an war es uns ein Anliegen alle Pläne und Dokumente öffentlich zugänglich zu machen, so dass sich jeder ein «OpenSlide» bauen kann. Dieses Projekt eignet sich sehr dafür, da wir auf herkömmliche Produkte gesetzt haben, die sich jeder bestellen kann. So kann also jemand mit Hilfe unserer Anleitung, Pläne und Code einen eigenen Slider bauen.

Es ist aber für andere auch möglich unser Code anzupassen und eine Einfügung in das Projekt zu beantragen. So kann das Projekt auch nach der Vertiefungsarbeit stetig verbessert werden.

### 11.1. GitHub

GitHub ist eine webbasierte Plattform für die Versionsverwaltung von Quellcode und bietet Funktionen für Zusammenarbeit und Nachverfolgung von Änderungen in Softwareprojekten. Entwickler können ihre Projekte auf GitHub verwalten, gemeinsam arbeiten und Features wie Pull-Requests und Wikis nutzen.

Genau diese Funktionen nutzen wir für Opensilde intensiv. Daher haben wir sämtliche relevanten Daten in ein GitHub-Repository hochgeladen.

Abbildung 30 Openslide Github Repository

### 20 Veröffentlichung, Selbst erstellt

Tim Reber, Noé Krebs | 36

### 11.2. Erreichbarkeit

Das Repository ist für jeden auf GitHub unter github.com/sempex/openslide zugänglich, unter openslide.noekrebs.ch, ist das Web UI erreichbar.

Mit diesen beiden Quellen ist es möglich, den Slider nachzubauen und anschliessend zu steuern.

Tim und Noé wünschen viel Spass beim Nachbauen und Experimentieren!

Tim Reber, Noé Krebs | 37

## 12. Glossar²¹

Begriff | Definition / Erklärung
3D Drucker | 3D-Druck ist ein Fertigungsverfahren, bei dem dreidimensionale Ob-jekte schichtweise aufgebaut werden, indem Materialien wie Kunststoff oder Metall schichtweise aufgetragen oder verfestigt werden.
Frontend Framework | Frontend Frameworks erleichtern die Entwicklung sogenannter Single-Page-Webanwendungen.
Github | GitHub ist eine Plattform zur Speicherung von Code, für Versionskon-trolle und Zusammenarbeit.
Kamera-Slider | Ein Kamera-Slider ist ein Werkzeug, mit dem Sie Ihre Kamera sanft und gleichmässig entlang eines Schienensystems bewegen können.
Open Source | Open Source bezieht sich auf Software, deren Quellcode frei verfügbar ist, so dass Benutzer ihn anzeigen, verwenden, ändern und verteilen können. Es kann sich hierbei auch um andere digitale Produkte han-deln.
Pull Requests | Ein Pull Request ist eine Anfrage, die ein Entwickler stellt, um Änderun-gen, die er an einem Repository vorgenommen hat, in das Original-Repository zu integrieren.
Repository | Ein Repository ist das grundlegendste Element auf GitHub. Es ist ein Ort, an dem man Code, Dateien und die Versionshistorie jeder Datei speichern kann.

### 21 Glossar, Selbst erstellt

Tim Reber, Noé Krebs | 38

## 13. Abkürzungsverzeichnis²²

Abkürzung | Definition / Erklärung
API | Application Programming Interfaces
CAD | Computer Aided Design
PCB | Printed Circuit Board
PLA | Polylactide

### 22 Abkürzungsverzeichnis, Selbst erstellt

Tim Reber, Noé Krebs | 39

## 14. Schlusswort²³

Der Gesamteindruck der Umsetzung dieses Projekts ist sehr positiv. Wir haben dabei eine Menge neue Sachen gelernt, was aber auch relativ zeitaufwendig war. Wir mussten sehr viele verschiedene Dinge in kürzester Zeit lernen und umsetzen. Das Projekt war vom Aufwand her sehr gross, was wir aber mit unserer Begeisterung und Leidenschaft für das Projekt wieder wettmachen konnten. Wir haben selbst eine Riesenfreude an dem fertigen Ergebnis und können dies nun auch beim Produzieren von Videos verwenden.

Wir haben meistens zusammengearbeitet, was sich enorm bewährt hat. Durch die stetige Zusammenarbeit hatten wir allgemein mehr Spass an der Umsetzung und wir kamen viel schneller voran, da wir zu zweit einer Menge Probleme vorbeugen konnten. Wir konnten uns stetig gegenseitig mit unserem Wissen ergänzen.

Mit der fertigen Umsetzung des Projekts haben wir den Grundstein gelegt, um in Zukunft ein OpenSource Projekt zu pflegen, wo verschiedenste Leute ihren eigenen «OpenSlide» bauen können, da wir alle Baupläne, Komponenten und Sourcecode kostenlos zur Verfügung stellen. Als Informatiker profitieren wir jeden Tag von kostenlosen Inhalten und können somit auch etwas zurückgeben.

### 14.1. Abweichung von den Zielen

Wir haben Ziel drei etwas anders umgesetzt als ursprünglich geplant. Wir haben ausführliche Tests mit unserem Slider durchgeführt und in einem Bewertungsraster dokumentiert, jedoch konnten wir diese Tests nicht mit einem anderen Slider vergleichen. Dafür haben wir jedoch eine zweite Tabelle erstellt, in der wir Fakten und Daten unseres Sliders mit Angaben zu anderen Slidern aus dem Internet verglichen. So können wir mit einer kleinen Abweichung zur ursprünglichen Planung das Ziel bestmöglich abdecken.

Der Kamera Slider ist momentan noch nicht mit dem Handy steuerbar, da dies mit der Implementation der seriellen Kommunikation aktuell nicht möglich ist. Dies möchten wir aber in Zukunft, wie im «weiteren Vorgehen» beschrieben, verbessern.

### 23 Schlusswort, Selbst erstellt

Tim Reber, Noé Krebs | 40

### 14.2. Weiteres Vorgehen

Wir werden auch nach der Vertiefungsarbeit an dem OpenSlide weiter arbeiten, da wir so begeistert davon sind. Wir planen, die Steuerung des Sliders kabellos zu konstruieren. Hierfür möchten wir die aktuelle kabelgebundene Kommunikation auf Bluetooth umstellen. So wäre auch die Steuerung mit einem Smartphone möglich.

Kurz vor Abschluss der Umsetzung fiel uns auf, dass die Befestigung der Kamera noch nicht optimal ist. Daher haben wir nach einer Lösung gesucht und einen Kugelkopf bestellt. Dieser ermöglicht eine einfachere Einstellung der Kameraposition. Leider wird er voraussichtlich erst nach der VA-Zeit eintreffen, sodass wir diese Verbesserung erst bei der Präsentation vorstellen können.

### 14.3. Bearbeitungsgrad

Bei jedem Hauptkapitel wurde der Bearbeitungsgrad (1., 2., …) angegeben. Falls eine Spezifizierung für ein Unterkapitel nötig wäre, wird bei diesem der Bearbeitungsgrad explizit angegeben. Ansonsten gilt die Angabe des Hauptkapitels für alle Unterkapitel.

Bilder, bei denen keine spezifische Quelle angegeben ist, wurden selbst erstellt. Bilder mit Quellen sind jeweils mit einem Bearbeitungsgrad gekennzeichnet.

Tim Reber, Noé Krebs | 41

## 15. Abbildungsverzeichnis²⁴

### 24 Abbildungsverzeichnis, Selbst erstellt

Tim Reber, Noé Krebs | 42

## 16. Tabellenverzeichnis²⁵

### 25 Tabellenverzeichnis, Selbst erstellt

Tim Reber, Noé Krebs | 43

## 17. Schlusserklärung

„Hiermit versichern wir, dass die vorliegende Arbeit selbstständig angefertigt wurde. Alle Quellen und beanspruchten Hilfeleistungen, welche den Inhalt der Arbeit beeinflussen, sind am Ende eines Kapitels deklariert. Die Erarbeitungsgrade entsprechen der Wahrheit. Wir sind uns bewusst, dass der Einsatz von KI-Schreibwerkzeugen keine Garantie für die Qualität von Inhalten und Text darstellt.»

Tim Reber | Noe Krebs
Unterschrift | Unterschrift

Vertiefungsarbeit | OpenSlide - Kamera Slider
Tim Reber, Noé Krebs | 44

## 18. Arbeitsjournal²⁶

### 26 Arbeitsjournal, Selbst erstellt

KW/Datum | Zeit | Wer | Tätigkeit | Ort | Details | Reflexion &Pendenzen
KW 42 19.10.2023 | 2h | Tim & Noé | - Planung der Grobplanung - Vorbereiten des Doku-ments | GIBB | Wir konnten einen Plan erstellen, wann wir welche Aufgaben erledi-gen möchten. Somit kennen wir die nächsten Schritte und wissen was wir in den folgenden Wochen alles zu tun haben. | Wir dokumentieren unser Kon-zept, und schliessen die Pla-nung des Projekts ab. Wenn dies fertig ist, können wir mit der Umsetzung unseres Pro-jekts beginnen.
KW 43 26.10.2023 | 2h | Tim & Noé | - Aufbau und formatieren des Dokuments | GIBB | Wir hatten einige Probleme mit der Formatierung und Nummerierung der Überschriften. Wir mussten vie-les neu erstellen, damit die Vorla-gen korrekt angewendet wurden. Nun sollte aber das Dokument kor-rekt sein und in Zukunft besser funktionieren. | Mit den ersten Arbeiten an dem Slider beginnen und diese gleich dokumentieren.
KW 44 01.11.2023 | 2h | Tim & Noé | - Initialisierung des Web-UI - Prototyp des Web-UI de-ployen - Dokumentation nachfüh-ren | GIBB | Es ist uns leicht gefallen die Anfor-derungen an das Web UI zu defi-nieren, da wir genau wussten, was wir brauchen. Schlussendlich ha-ben wir diese dann als Features dokumentiert. | Nächstes Mal werden wir be-reits mit dem Zusammenbau der Teile beginnen.
KW 45 | 4h | Tim & Noé | - Beginn der Umsetzung - Dokumentation nachfüh-ren - Anpassung Arduino Code | Su-mis-wald | Zu Beginn sind wir sehr gut voran-gekommen. Allerdings haben wir lange nach der korrekten Verbin-dung zwischen Stepper Motor und Driver gesucht. Wie sich aber spä-ter herausgestellt hat, war das ei-gentliche Problem eine Fehlkonfi-guration im Code. Wir werden in Zukunft noch besser darauf achten, | Wir haben alle Teile kontrolliert und mit dem Zusammenbau begonnen. Der Motor kann nun via Driver mit dem Arduino angesteuert werden. Beispiel code im Arduino Skript einge-fügt, um die Funktionalität zu testen.

Vertiefungsarbeit | OpenSlide - Kamera Slider
Tim Reber, Noé Krebs | 45
| | | | | dass wir jeden Arbeitsschritt genau kontrollieren.
KW46 | 2h | Tim & Noé | - Dokumentation Umset-zung erster Teil - Rendern des 3D Modells - Slider in Web UI integrie-rern. - Anpassen des 3D Modells | GIBB | Wir haben begonnen, die Erfahrun-gen und Ereignisse von letzter Wo-che zu dokumentieren. Wir konnten das gerenderte 3D-Modell ins Web-UI integrieren, dies trägt dem Verständnis der Benut-zung der Oberfläche bei. | Es war spannend aufzuzeigen, was wir zusammengebaut ha-ben. Wir konnten viele Fort-schritte machen, mussten aber sehr viel löten, was zu diver-sen Kopfschmerzen führte. Das nächste Mal sollten wir eventuell eine Maske tragen.
KW47 | 2h | Tim &
Noé
- Arduino Logik
- 3D Print Einstellungen

GIBB Heute haben wir uns auf das Programmieren des Arduinos fokussiert. Wir haben den Stepper Motor angesteuert und erstmals mit dem Web UI verbunden.

Zu Beginn hatten wir einige Probleme mit der Steuerung über das Web-UI. Dank unserer eigens erstellten Debugging-Konsole, konnten wir
diese jedoch schnell und einfach beheben. Wir haben bereits eine solide Grundlage gelegt, aber es gibt noch einiges zu tun. Das nächste Mal werden wir mit der Programmierung fortfahren und möglicherweise die Kalibrierungsmethode implementieren. Es gelingt uns gut, zusammen an denselben Aufgaben zu arbeiten.
KW 48 | 2h | Tim &
Noé
- Slider Kalibrierung | GIBB | Heute haben wir den Code ge-
schrieben, der für die Kalibrierung des Sliders nötig ist.

Wir haben zuerst zusammen
auf Papier skizziert, wie die Kalibrierung genau aufgebaut sein soll. Bei diesem Prozess haben wir beide unser Wissen

Vertiefungsarbeit | OpenSlide - Kamera Slider

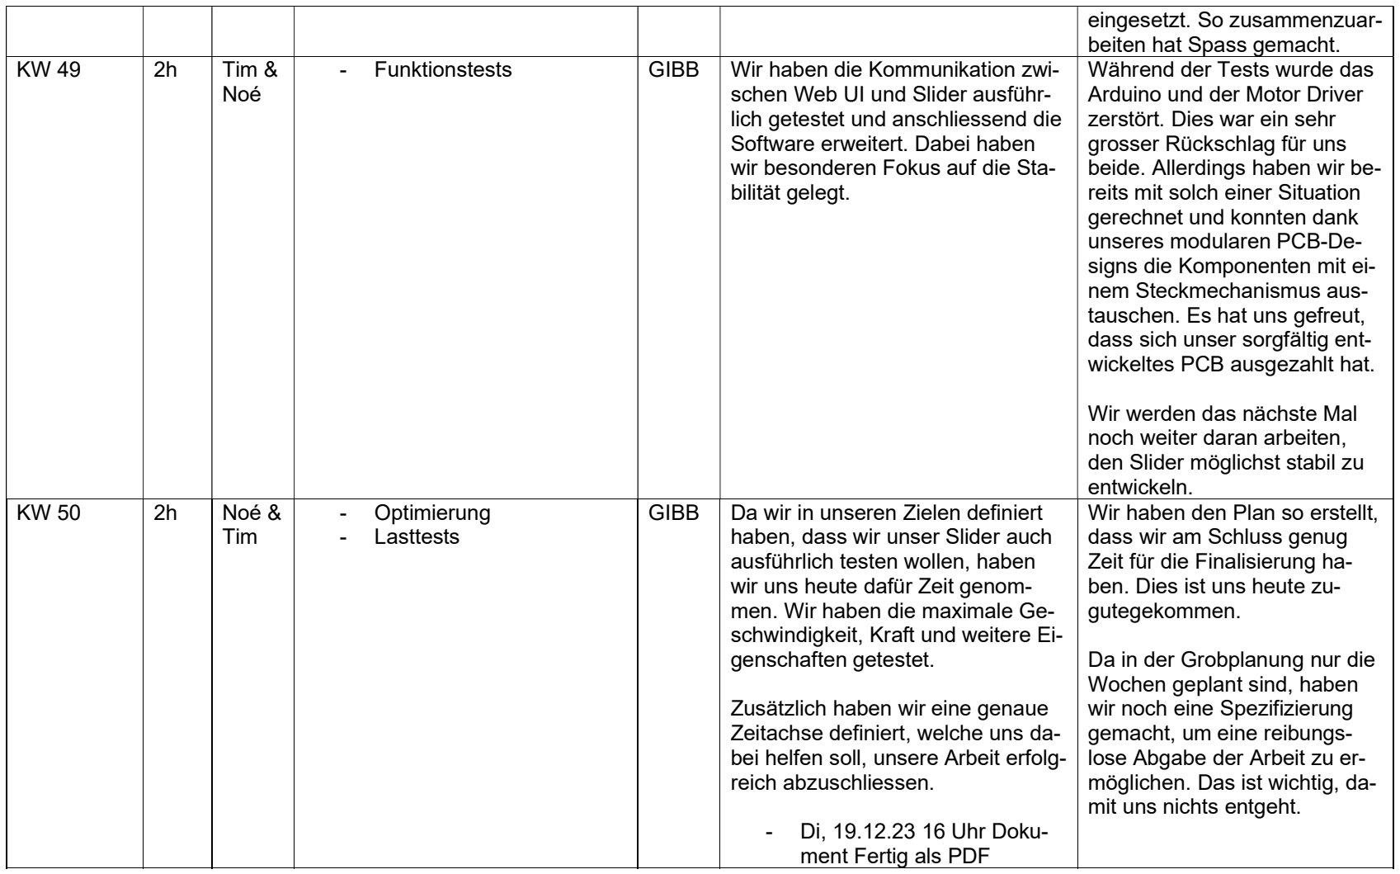
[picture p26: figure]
eingesetzt. So zusammenzuar- beiten hat Spass gemacht.; Tim &; Noé; schen Web UI und Slider ausführ- lich getestet und anschliessend die Software erweitert. Dabei haben wir besonderen Fokus auf die Sta- bilität gelegt.; Während der Tests wurde das Arduino und der Motor Driver zerstört. Dies war ein sehr grosser Rückschlag für uns beide. Allerdings haben wir be- reits mit solch einer Situation gerechnet und konnten dank unseres modularen PCB-De- signs die Komponenten mit ei- nem Steckmechanismus aus- tauschen. Es hat uns gefreut, dass sich unser sorgfältig ent- wickeltes PCB ausgezahlt hat.; Wir werden das nächste Mal noch weiter daran arbeiten, den Slider möglichst stabil zu entwickeln.; Noé &; Tim; - Optimierung - Lasttests; GIBB; Da wir in unseren Zielen definiert; haben, dass wir unser Slider auch ausführlich testen wollen, haben wir uns heute dafür Zeit genom- men. Wir haben die maximale Ge- schwindigkeit, Kraft und weitere Ei- genschaften getestet.; Zusätzlich haben wir eine genaue Zeitachse definiert, welche uns da- bei helfen soll, unsere Arbeit erfolg- reich abzuschliessen.; - Di, 19.12.23 16 Uhr Doku- ment Fertig als PDF; Wir haben den Plan so erstellt, dass wir am Schluss genug Zeit für die Finalisierung ha- ben. Dies ist uns heute zu- gutegekommen.; Da in der Grobplanung nur die Wochen geplant sind, haben wir noch eine Spezifizierung gemacht, um eine reibungs- lose Abgabe der Arbeit zu er- möglichen. Das ist wichtig, da- mit uns nichts entgeht.

Tim Reber, Noé Krebs | 46
- Funktionstests | GIBB | Wir haben die Kommunikation zwi-

Vertiefungsarbeit | OpenSlide - Kamera Slider
Tim Reber, Noé Krebs | 47
- Mi 20.12.23 ausdrucken
und heften in der Firma.
- Do 21.12.23 Abgabe

Tim Reber, Noé Krebs | 48

## 19. Anhang

All unser Code und sonstige Dateien sind wie beschrieben auf GitHub zu finden.

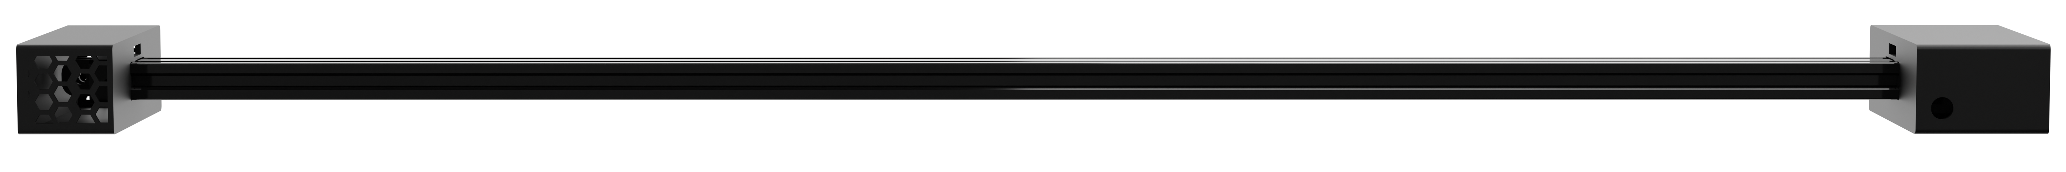
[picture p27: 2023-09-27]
cad/renders/v4.png

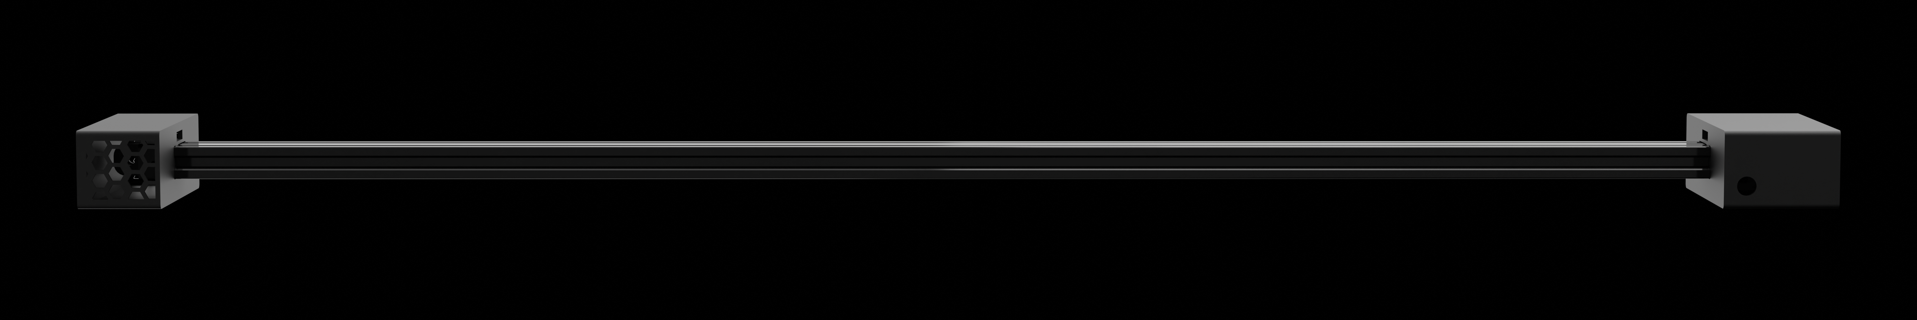
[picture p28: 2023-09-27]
cad/renders/v1.png

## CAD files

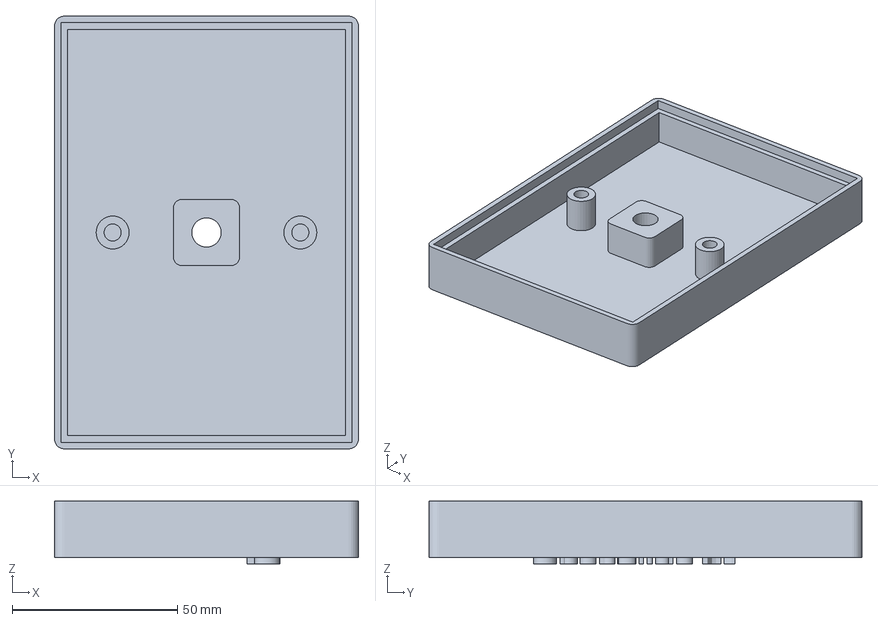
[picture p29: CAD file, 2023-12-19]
cad/schlitten v2.3mf
92.0 x 131.0 x 19.0 mm

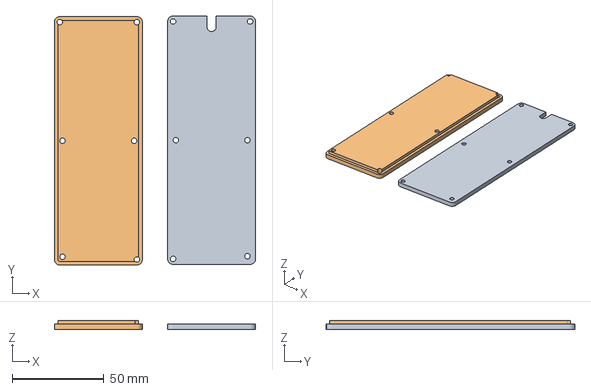
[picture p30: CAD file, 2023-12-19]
cad/Slider v15.3mf
109.8 x 135.7 x 5.00 mm
Körper11
Körper16

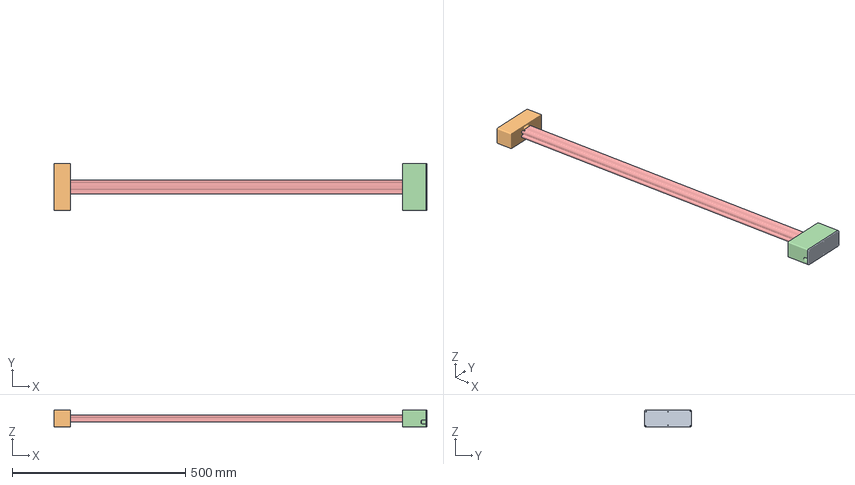
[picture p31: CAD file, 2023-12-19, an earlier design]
cad/Slider v14.3mf
1076.0 x 135.4 x 48.0 mm
Körper11
Körper13
Körper6
Körper7
Rail

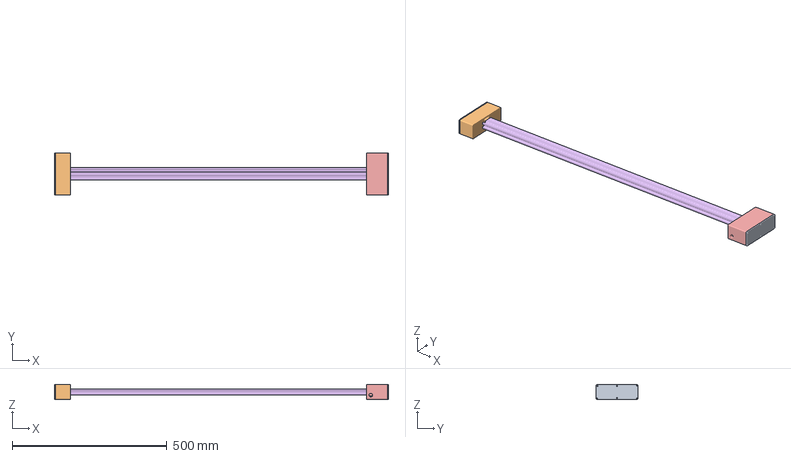
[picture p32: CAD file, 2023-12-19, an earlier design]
cad/Slider v11.3mf
1079.0 x 135.4 x 48.0 mm
Körper11
Körper13
Körper16
Körper6
Körper7
Rail

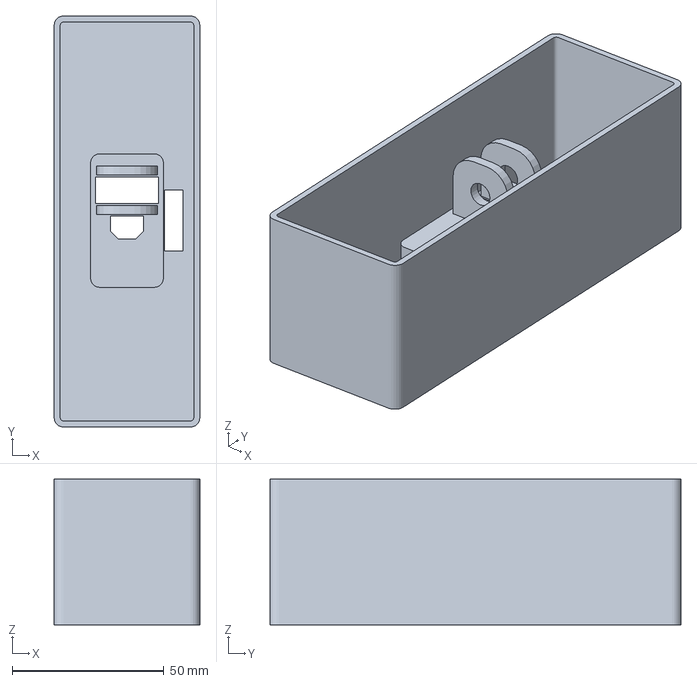
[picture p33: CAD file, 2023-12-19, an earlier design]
cad/Slider v13.3mf
48.0 x 135.4 x 48.0 mm

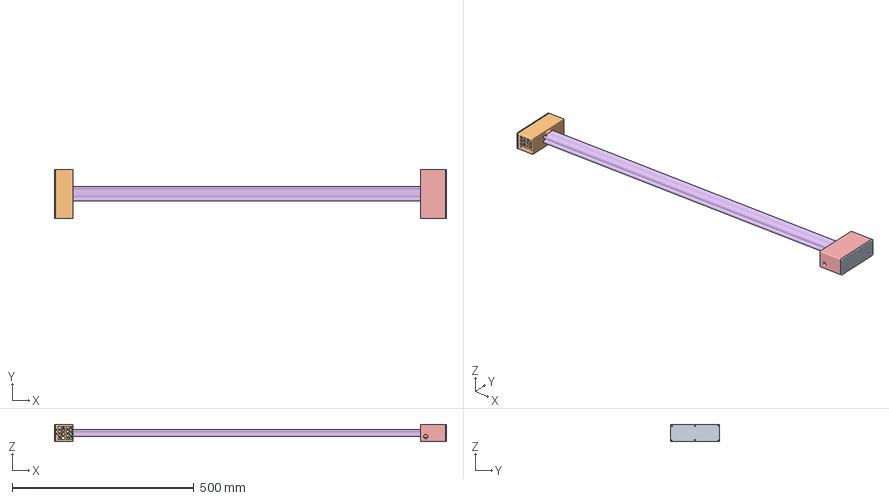
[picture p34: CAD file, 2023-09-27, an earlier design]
cad/Slider v9.3mf
1079.0 x 135.4 x 48.0 mm
Körper11
Körper13
Körper16
Körper6
Körper7
Rail

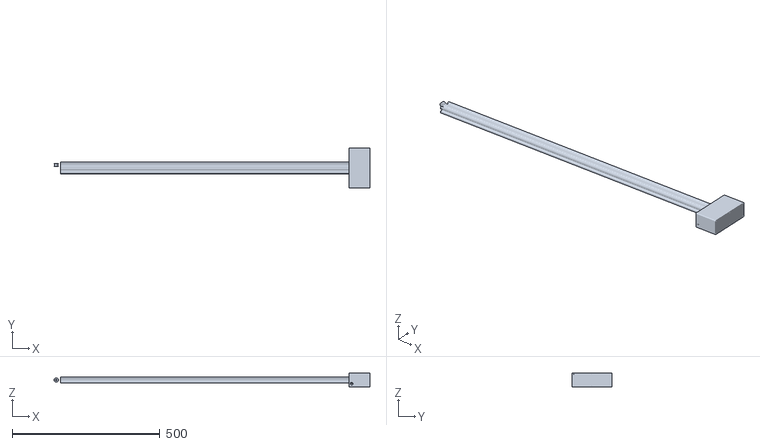
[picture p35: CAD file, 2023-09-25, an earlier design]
cad/Slider v6.stl
1069.5 x 135.4 x 48.0

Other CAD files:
cad/Slider v4.stl
cad/Slider v5.f3d
cad/Slider v9.stl
cad/renders/slider.blend
cad/schlitten v2.f3d

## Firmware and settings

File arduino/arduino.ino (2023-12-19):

#include <AccelStepper.h>

#define stepPin 5
#define dirPin 4
#define btnOne 14
#define btnTwo 13

const byte MAXIMUM_INPUT_LENGTH = 50;
const int  MAX_STEPS = 3000;
const char PKG_START = '<';
const char PKG_END = '>';
const char PKG_COMM_DELIMITER = ':';
const char PKG_DATA_DELIMITER = ',';
const char PKG_KEY_VALUE_DELIMITER = '=';

String input = "";

struct Message
{
  String type;
  String keys[10];   // Adjust the size according to your needs
  String values[10]; // Adjust the size according to your needs
  int dataCount;
};


int start = 0;
int end = 0;

AccelStepper stepper(AccelStepper::DRIVER, stepPin, dirPin);


void calibrate() {
  stepper.setMaxSpeed(400);
  stepper.setAcceleration(4000);
  stepper.moveTo(20000);
  while (digitalRead(btnOne) == HIGH) {
    stepper.run();
    yield();
  }

  stepper.setCurrentPosition(0);
  stepper.moveTo(-20000);
  while (digitalRead(btnTwo) == HIGH) {
    stepper.run();
    yield();
  }
  end = stepper.currentPosition();
  goTo(50);
  Serial.println("<OK:Endposition=set>");
  Serial.println("<OK:Startposition=set>");
  
}

void setup() {
  Serial.begin(9600);
  stepper.setMaxSpeed(750);
  stepper.setAcceleration(4000);
  pinMode(btnOne, INPUT);
  pinMode(btnTwo, INPUT);
}

void goTo(int persPos) {
  persPos = map(persPos, 0, 100, start - 100, end +100);
  
  stepper.stop();
  stepper.moveTo(persPos);
  
  while (stepper.distanceToGo() != 0) {
    stepper.run();  // Add a small delay to avoid busy-waiting
    yield();
  }
}

void emergencyOut(){
  if (digitalRead(btnTwo) == LOW || digitalRead(btnOne) == LOW) {
    stepper.stop();
    Serial.println("<ERROR:message=Unexpected endpoint hit!>");
  }  
}


void loop()
{
  input = "";
  bool startMarkerFound = false; // Flag to track whether the start marker is found

  // Wait for the start marker
  while (Serial.available())
  {
    char currentChar = Serial.read();
    if (currentChar == PKG_START)
    {
      startMarkerFound = true;
      break;
    }
  }

  // Continue reading if the start marker is found
  if (startMarkerFound)
  {
    // Read the input until the end marker or maximum length is reached
    char currentInput;
    unsigned long startTime = millis();
    while (millis() - startTime < 1000)
    { // Timeout after 1 second
      if (Serial.available())
      {
        currentInput = Serial.read();
        if (currentInput == PKG_END || input.length() >= MAXIMUM_INPUT_LENGTH)
        {
          break; // Exit the loop when the end marker is found or max length reached
        }
        input += currentInput;
      }
    }
    // Print the received input
    Message res = parse(input);
    Serial.println("<OK:pos=19>"); // Send an acknowledgement

    if (res.type == "CONN")
    {
      Serial.println("<CONN:v=1,name=OpenSlide>");
    }
    else if (res.type == "CALIBRATE") {
      calibrate();
      Serial.println("<OK:Calibrated>");
    }
    else if (res.type == "MOVE")
    {
      int start = res.values[0].toInt();
      int end = res.values[1].toInt();

      goTo(start);
      delay(1000);
      goTo(end);
      
      char buffer[30];
      
      sprintf(buffer, "<OK:will move=%d>", start);
      
      Serial.println(buffer);
    }
    else if (res.type == "GET")
    {
      Serial.println("<OK:pos=19>");
    }
    else if (res.type == "SPEED") {
      int speed = map(res.values[0].toInt(), 0, 100, 5, 3000);
      stepper.setMaxSpeed(speed);
      stepper.setAcceleration(speed * 4);
    }
    else if (res.type == "MOVEL")
    {
      int position = stepper.currentPosition();
      position = position + end * (res.values[0].toInt() / 10);
      goTo(position);

    }
    else if (res.type == "MOVER")
    {
      Serial.println("<OK:pos=19>");
    }
    else if (res.type == "DISC")
    {
      Serial.println("<OK:pos=19>");
    }
    else if (res.type == "PING")
    {
      Serial.println("<OK:pos=19>");
    }
    else if (res.type == "ERROR")
    {
      Serial.println("<OK:pos=19>");
    }
    else
    {
      Serial.println("<ERROR:pos=19>");
    }
  }
}

Message parse(const String &input)
{
  int delimiterPos = input.indexOf(PKG_COMM_DELIMITER);
  if (delimiterPos == -1)
  {
    return {}; // Invalid input
  }

  String type = input.substring(0, delimiterPos);
  String raw = input.substring(delimiterPos + 1);

  Message message;
  message.type = type;
  message.dataCount = 0;

  int startPos = 0;
  while (startPos != -1)
  {
    int keyValueDelimiterPos = raw.indexOf(PKG_KEY_VALUE_DELIMITER, startPos);
    if (keyValueDelimiterPos == -1)
    {
      break; // No more key-value pairs
    }

    String key = raw.substring(startPos, keyValueDelimiterPos);
    startPos = keyValueDelimiterPos + 1;

    int dataDelimiterPos = raw.indexOf(PKG_DATA_DELIMITER, startPos);
    String value = raw.substring(startPos, dataDelimiterPos == -1 ? raw.length() : dataDelimiterPos);
    startPos = (dataDelimiterPos == -1) ? -1 : dataDelimiterPos + 1;

    message.keys[message.dataCount] = key;
    message.values[message.dataCount] = value;
    message.dataCount++;

    if (message.dataCount >= 10)
    {
      break; // Maximum number of key-value pairs reached
    }
  }
  return message;
}

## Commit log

2023-09-15 chore: forward button
2023-09-18 chore: add revert button
2023-09-18 chore: edit swap button design
2023-09-20 CAD Files
    [Slider v4.stl]
2023-09-25 new cad
    [Slider v5.f3d, Slider v6.stl]
2023-09-27 new slider version
    [Slider v9.stl]
2023-09-27 slider image
    [slider.blend]
2023-11-15 Update arduino.ino
    Stepper control
2023-12-07 Update arduino.ino may work may not
2023-12-09 implement calibration
2023-12-09 chore: add calibrate button
2023-12-10 center buttons
2023-12-19 Fix calibration issue
